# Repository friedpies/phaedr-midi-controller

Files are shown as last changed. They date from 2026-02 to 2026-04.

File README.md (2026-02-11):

# Phaedr MIDI Controller

Phaedr MIDI Controller

See the [hackaday](https://hackaday.io/project/204994-phaedr-midi-controller) project

USB MIDI controller firmware for Teensy 3.5. A custom control surface with 16 grid buttons, 8 track buttons, 8 rotary knobs, and 8 sliders — designed for bidirectional communication with a DAW.

This project started in 2021 as a pandemic side project — custom PCB, custom enclosure, and firmware from scratch. The goal was less about building the most practical MIDI controller and more about a fun design challenge: use a Teensy 3.5 and max out every available pin. I got distracted along the way and never finished it, but now with the help of Claude Code I'm eager to wrap up the loose ends. The Teensy 3.5 is largely deprecated at this point, though most of the firmware should be portable to a Teensy 4.1 with pin remapping.

## Features

- USB MIDI over serial — no external MIDI interface needed
- Bidirectional CC feedback: button LEDs reflect DAW state
- PWM LED fading via SoftPWM
- Debounced button input via Bounce2
- Noise-filtered analog inputs for knobs and sliders

## Hardware

- **MCU:** Teensy 3.5
- **16 grid buttons** with individual LEDs (CC 102–117)
- **8 track buttons** with individual LEDs (CC 20–27)
- **8 rotary knobs** (CC 14–15, 28–31, 118–119)
- **8 sliders** (CC 3, 9, 85–90)

All MIDI messages use channel 1.

## Build

Requires [PlatformIO](https://platformio.org/).

```sh
# Build
pio run

# Upload to Teensy
pio run --target upload

# Serial monitor (for debug output)
pio device monitor
```

## Dependencies

Managed automatically by PlatformIO:

- [Bounce2](https://github.com/thomasfredericks/Bounce2) — button debouncing
- [SoftPWM](https://github.com/bhagman/SoftPWM) — PWM LED control

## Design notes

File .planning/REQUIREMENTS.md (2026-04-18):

# Requirements: Phaedr MIDI Controller

**Defined:** 2026-02-21
**Core Value:** A controller that feels alive — LEDs accurately reflect DAW state, a beat chaser pulses with the music, and every interaction has immediate, satisfying visual feedback.

## v1 Requirements

### MCU Protocol Foundation

- [x] **MCU-01**: Firmware completes the 4-step MCU SysEx handshake with Logic Pro (Device Query → Host Connection Query → Host Connection Reply → Confirmation) within 300ms
- [x] **MCU-02**: Logic Pro recognizes the controller as a Mackie Control Universal surface and begins sending bidirectional MIDI feedback
- [x] **MCU-03**: Channel strip buttons (REC, SOLO, MUTE, SELECT) send MCU Note Bang messages on MIDI channel 1 using note numbers 0–31
- [x] **MCU-04**: Transport buttons (Rewind, FF, Stop, Play, Record) send MCU Note Bang messages using note numbers 91–95
- [x] **MCU-05**: Sliders (faders) send 14-bit pitch bend on MIDI channels 1–8, not CC messages
- [x] **MCU-06**: Knobs send CC 16–23 (VPot encoder messages) per MCU protocol

### LED State Feedback

- [x] **LED-01**: Channel strip REC/SOLO/MUTE/SELECT LEDs update in response to Note On/Off messages from Logic (velocity 127 = on, 1 = blink, 0 = off)
- [x] **LED-02**: Transport state LEDs (Play, Record) reflect real Logic Pro state via incoming Note On/Off
- [ ] **LED-03**: Loop active, punch in/out, and metronome toggle states reflected in grid button LEDs
- [x] **LED-04**: ButtonRegistry extended with Note-to-Button lookup alongside existing CC-to-Button map

### Pickup Mode

- [x] **PICK-01**: Each fader tracks last known DAW value received via incoming pitch bend on MIDI channels 1–8
- [x] **PICK-02**: Fader MIDI output is suppressed until physical position crosses through (or within tolerance of) the DAW value
- [x] **PICK-03**: Channel button LED blinks (500ms period) while fader is out of sync with DAW value
- [x] **PICK-04**: LED blink stops and fader becomes active exactly when pickup occurs
- [x] **PICK-05**: All 8 faders re-enter pickup mode (blink) on every bank switch
- [x] **PICK-06**: Boundary edge case handled: faders at 0 or 127 pick up immediately if DAW value matches

### Grid Transport Layout

- [ ] **GRID-01**: Grid row 4 bottom: Shift (btn 13, LED), Record (btn 14, LED), Stop (btn 15, no LED), Play (btn 16, no LED) mapped to MCU transport note numbers
- [ ] **GRID-02**: Grid rows 1–3 (12 buttons): Bank Prev/Next, Loop Toggle, Punch In/Out, cursor navigation (Up/Down/Left/Right), Metronome/Click Toggle, Zoom mapped to MCU note numbers
- [ ] **GRID-03**: Shift button (btn 13) enables secondary functions when held (firmware-local state, not sent to DAW)
- [ ] **GRID-04**: Shift + button combinations send secondary MCU note messages for mode buttons

### Beat Chaser

- [ ] **BEAT-01**: A single LED sweeps across the 4×4 grid (14 LEDs with LEDs only) per beat, advancing one cell per beat
- [ ] **BEAT-02**: Beat timing derived from MIDI clock: counter increments on each of Logic's 24 PPQN clock pulses; one LED advances every 24 pulses
- [ ] **BEAT-03**: Beat chaser starts from cell 0 on MIDI Start (0xFA) message
- [ ] **BEAT-04**: Beat chaser resumes without resetting on MIDI Continue (0xFB) message
- [ ] **BEAT-05**: Beat chaser pauses on MIDI Stop (0xFC) message
- [ ] **BEAT-06**: Beat chaser never overwrites transport-owned LEDs (Play, Record, Stop, Shift)
- [ ] **BEAT-07**: All clock and animation logic is non-blocking (no delay()); uses millis() state machines

### Startup Animations

- [ ] **ANIM-01**: Compile-time config variable selects one of 4 startup animation styles
- [ ] **ANIM-02**: Cascade — LEDs sweep row by row, left to right, across the grid
- [ ] **ANIM-03**: Ripple — LEDs expand outward from center of grid
- [ ] **ANIM-04**: Sparkle — LEDs flicker in random order then settle
- [ ] **ANIM-05**: Flash — all LEDs blast on at once, then fade to correct state
- [ ] **ANIM-06**: After animation completes, LEDs settle to reflect current DAW state (not a fixed off state)
- [ ] **ANIM-07**: Startup animation is non-blocking — MIDI messages received during animation are processed

### Action Animations

- [ ] **ACT-01**: Record start: Record button LED pulses (blink pattern distinct from pickup blink)
- [ ] **ACT-02**: Bank switch: brief cascade sweep across 8 channel buttons (left to right)
- [ ] **ACT-03**: Shift held: subtle dimmed glow on non-active, non-transport LEDs
- [ ] **ACT-04**: All action animations are non-blocking; don't interrupt MIDI processing

### Power & Boot

- [x] **PWR-01**: A compile-time constant `LED_MAX_BRIGHTNESS` (default 180, range 0–255) in `src/pinDefines.h` caps the SoftPWM value used for all "LED on" states; `MCUButton::setLedState(127)` sets brightness to `LED_MAX_BRIGHTNESS` (not 255), ensuring the 24-LED array stays within USB 500mA power budget (Teensy ~150mA + 24 LEDs at ≤14mA avg = ~490mA max)
- [x] **BOOT-01**: On power-on, a cascade startup animation lights each LED in sequence (K1→K16 grid row by row, then P1→P8 track buttons) and turns all off before MIDI callback registration; animation is a blocking call in `setup()` before `usbMIDI` handlers are registered, completing within 2 seconds

### Codebase Cleanup (Prerequisites)

- [x] **FIX-01**: Fix copy-by-value Button bug in `inputManager.cpp:25` — use pointer or reference so DAW-driven `setLedState()` calls actually update physical LEDs
- [x] **FIX-02**: Remove `Serial.println("CONTROL CHANGE")` from MIDI callbacks — debug output causes timing jitter at 24 PPQN clock rates

## v2 Requirements

### Configuration

- **CONF-01**: Startup animation style selectable at runtime via button combo (no recompile needed)
- **CONF-02**: MIDI channel configurable for multi-surface Logic Pro setups

### Extended Grid Mappings

- **EXT-01**: MIDI channel 2–16 support for multi-surface configurations
- **EXT-02**: Custom CC mapping mode alongside MCU protocol (legacy compatibility)

### VPot Ring Display

- **VPT-01**: Parse incoming VPot ring CC (48–55) from Logic and store per-channel state for future display use

## Out of Scope

| Feature | Reason |
|---|---|
| Motorized faders | Hardware limitation — Teensy 3.5 PCB has no motor driver |
| RGB / multi-color LEDs | All LEDs are single color; no color hardware available |
| DIN MIDI | USB MIDI only — no DIN connector on PCB |
| EEPROM persistence | All state volatile; resets on power cycle (explicitly out of scope in PROJECT.md) |
| Ableton Live / other DAWs | Logic Pro MCU only for this milestone |
| VPot LED rings | This hardware has no physical VPot ring LEDs |
| Unit tests / test framework | No test infrastructure in place; validation is manual + hardware-in-loop |

## Traceability

| Requirement | Phase | Status |
|---|---|---|
| FIX-01 | Phase 1 | Pending |
| FIX-02 | Phase 1 | Pending |
| MCU-01 | Phase 1 | Complete |
| MCU-02 | Phase 1 | Complete |
| MCU-03 | Phase 1 | Complete |
| MCU-04 | Phase 1 | Complete |
| MCU-05 | Phase 1 | Complete |
| MCU-06 | Phase 1 | Complete |
| LED-01 | Phase 1 | Complete |
| LED-02 | Phase 1 | Complete |
| LED-03 | Phase 2 | Pending |
| LED-04 | Phase 1 | Complete |
| PWR-01 | Phase 1 | Complete |
| BOOT-01 | Phase 1 | Complete |
| PICK-01 | Phase 2 | Complete |
| PICK-02 | Phase 2 | Complete |
| PICK-03 | Phase 2 | Complete |
| PICK-04 | Phase 2 | Complete |
| PICK-05 | Phase 2 | Complete |
| PICK-06 | Phase 2 | Complete |
| GRID-01 | Phase 3 | Pending |
| GRID-02 | Phase 3 | Pending |
| GRID-03 | Phase 3 | Pending |
| GRID-04 | Phase 3 | Pending |
| BEAT-01 | Phase 4 | Pending |
| BEAT-02 | Phase 4 | Pending |
| BEAT-03 | Phase 4 | Pending |
| BEAT-04 | Phase 4 | Pending |
| BEAT-05 | Phase 4 | Pending |
| BEAT-06 | Phase 4 | Pending |
| BEAT-07 | Phase 4 | Pending |
| ANIM-01 | Phase 4 | Pending |
| ANIM-02 | Phase 4 | Pending |
| ANIM-03 | Phase 4 | Pending |
| ANIM-04 | Phase 4 | Pending |
| ANIM-05 | Phase 4 | Pending |
| ANIM-06 | Phase 4 | Pending |
| ANIM-07 | Phase 4 | Pending |
| ACT-01 | Phase 4 | Pending |
| ACT-02 | Phase 4 | Pending |
| ACT-03 | Phase 4 | Pending |
| ACT-04 | Phase 4 | Pending |

**Coverage:**
- v1 requirements: 42 total
- Mapped to phases: 42
- Unmapped: 0 ✓

---
*Requirements defined: 2026-02-21*
*Last updated: 2026-02-21 — added PWR-01 (USB current budget) and BOOT-01 (startup animation) to Phase 1*

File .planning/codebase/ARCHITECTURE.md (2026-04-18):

# Architecture

**Analysis Date:** 2026-03-02

## Pattern Overview

**Overall:** Arduino firmware using a hardware abstraction layer (HAL) pattern with event-driven state machines. The firmware is a unidirectional controller that sends input state to Logic Pro DAW and receives feedback via MIDI to update LED displays.

**Key Characteristics:**
- Polled input reading (buttons, knobs, faders) in main loop with debouncing
- USB MIDI bidirectional communication for command/feedback
- MCU protocol handshake for Logic Pro recognition (SysEx-based)
- Asynchronous LED animation engine (ripple effect) running concurrently with input
- Pickup mode and bank switching for fader synchronization with DAW state
- Stateful blink FSM for channel strip button feedback

## Layers

**Hardware Abstraction Layer (Input Devices):**
- Purpose: Encapsulate physical input reading and filtering
- Location: `src/button.h/cpp`, `src/mcuButton.h/cpp`, `src/potentiometer.h/cpp`, `src/fader.h/cpp`
- Contains: `Button` (legacy), `MCUButton` (MCU protocol), `Potentiometer` (knobs/sliders), `Fader` (pitch bend with pickup mode)
- Depends on: Arduino core, Bounce2 (debouncing), SoftPWM (LED control)
- Used by: `InputManager`

**Input Management & Control Layer:**
- Purpose: Central orchestrator for all inputs; polls hardware, manages state machines, routes MIDI output
- Location: `src/inputManager.h/cpp`
- Contains: Input arrays (grid buttons, track buttons, knobs, faders), ripple animation FSM, track selection state, NoteRegistry
- Depends on: All HAL input classes, `NoteRegistry`, `MCUButton`
- Used by: `main.cpp`

**Protocol & Feedback Layer:**
- Purpose: Handles MCU handshake, maps incoming MIDI to hardware feedback
- Location: `src/mcuProtocol.h/cpp`, `src/noteRegistry.h/cpp`, `src/mcuConfig.h`
- Contains: MCU SysEx handshake state machine, note-to-button mapping registry
- Depends on: Arduino core, `MCUButton`
- Used by: `main.cpp`, `InputManager`

**Entry Point & Main Loop:**
- Purpose: Initialize firmware, register MIDI handlers, orchestrate update cycle
- Location: `src/main.cpp`
- Contains: Startup animation, MIDI callback handlers (SysEx, NoteOn/Off, PitchBend), main loop orchestration
- Depends on: All other modules
- Used by: Arduino runtime

## Data Flow

**Input → MIDI Output Path:**

1. `loop()` calls `inputManager.readAll()`
2. For each button (grid, track):
   - `MCUButton::read()` polls Bounce2 debouncer
   - On press (fell), sends `NoteOn(noteNum, 127)` + `NoteOff(noteNum, 0)` to DAW
3. For each knob:
   - `Potentiometer::read()` samples ADC, computes relative delta (MCU VPot format)
   - Sends relative CC (0x01-0x3F for CW, 0x41-0x7F for CCW) on CC 16-23
4. For each fader:
   - `Fader::read()` samples ADC, maps to 14-bit value
   - In SYNCED state: sends `PitchBend` on MIDI channels 1-8
   - In OUT_OF_SYNC (bank switch): waits for crossover, optionally blinks channel button

**MIDI Feedback → LED Update Path:**

1. `usbMIDI.read()` in `loop()` dispatches incoming MIDI to registered handlers
2. `handleNoteOn()` / `handleNoteOff()` → `inputManager.handleNoteMessage()`
3. `inputManager` looks up note in `noteRegistry` → finds corresponding `MCUButton`
4. `MCUButton::setLedState(velocity)` sets SoftPWM brightness (0=off, 127=on, 1=blink FSM)
5. `loop()` calls `inputManager.updateBlinks()` to advance all blink FSMs every iteration

**Fader Feedback → Pickup Mode Path:**

1. `handlePitchBend()` receives 14-bit fader position from Logic on channels 1-8
2. Routes to `Fader::setDawValue()`
3. `Fader` detects bank switch (DAW value far from physical position)
4. If bank switch detected, enters OUT_OF_SYNC state
5. On next `Fader::read()`, lazy-reveals blink on channel button
6. Blink frequency encodes distance to target (600ms far, 200ms close)
7. On crossover, `Fader` transitions to SYNCED, stops blink

**Pre-Handshake Ripple Animation:**

1. Before MCU handshake, `loop()` calls `inputManager.readIdle()` (debounce only)
2. `readIdle()` calls `poll()` on all buttons (no MIDI output, just debounce)
3. On press, triggers `triggerRipple(originIdx)` with LED position map
4. Computes Euclidean distance from origin to all 24 LEDs
5. Stores pre-computed brightness falloff curve
6. `loop()` calls `inputManager.updateRipple()` every iteration
7. Ripple timing: distance-based delay, then hold, then fade (all non-blocking, millis-based)

**State Management:**

- **Button State:** Debounce + LED state only (no toggle—Logic Pro drives LED state via feedback)
- **Fader State:** Last physical reading, last DAW value, pickup mode flag (SYNCED/OUT_OF_SYNC), blink reveal flag
- **Track Selection:** `InputManager._selectedTrack` tracks which fader/knob owns input focus
- **Ripple Animation:** Distance map, brightness map, timing, lit/faded flags per LED
- **MCU Handshake:** Completion flag, retry timer (5s intervals)
- **Blink FSM:** Per-button blink period, phase, last update time

## Key Abstractions

**MCUButton (Multi-Role Button):**
- Purpose: Encapsulate a physical button + optional LED with MCU protocol semantics
- Examples: `gridButtons[0-15]` (K1-K16), `trackButtons[0-7]` (P1-P8)
- Pattern: Dual-mode read (`read()` for MIDI output via note bang, `poll()` for debounce-only); LED state set via `setLedState(velocity)` from NoteRegistry feedback; blink FSM with non-blocking millis-based update

**Fader (MCU Pitch Bend with Pickup):**
- Purpose: Sync hardware fader with DAW value during bank switches, avoid sudden jumps
- Examples: `trackFaders[0-7]`
- Pattern: Two-state machine (SYNCED/OUT_OF_SYNC); lazy blink reveal on first movement; crossover detection with deadband + rail edge cases; distance-encoded blink period; automatic transition back to SYNCED on crossover

**Potentiometer (Dual-Mode Analog Input):**
- Purpose: Read analog knob/slider, output either absolute (7-bit MIDI) or relative (MCU VPot format)
- Examples: `trackKnobs[0-7]` (relative VPot CC 16-23), legacy sliders (absolute)
- Pattern: Threshold-based change detection (ANALOG_NOISE=3), supports inversion (used by knobs), accumulates relative deltas to handle coarse ADC resolution

**NoteRegistry (MIDI Note → Button Mapping):**
- Purpose: Route incoming NoteOn/Off from Logic to correct hardware button for LED feedback
- Examples: Logic sends note 24 (SELECT Ch1) → routes to P1 button → updates LED
- Pattern: `std::map<uint8_t, MCUButton*>` registry; fast O(log n) lookup on every MIDI message

**RippleState (Pre-Handshake Animation):**
- Purpose: Encapsulate 2D ripple wave animation state with distance-based timing
- Pattern: Pre-computed distance/brightness maps (computed once at trigger), non-blocking state tracking (lit/faded flags), time-gated LED updates using `millis()` delta

## Entry Points

**main() / setup():**
- Location: `src/main.cpp:78-91`
- Triggers: Arduino runtime calls setup() once on power-on
- Responsibilities: Initialize InputManager (which init SoftPWM), play startup animation, register MIDI callbacks with usbMIDI, start MCU protocol handshake

**loop():**
- Location: `src/main.cpp:93-104`
- Triggers: Arduino runtime calls continuously
- Responsibilities: Poll all inputs via `inputManager.readAll()` or `inputManager.readIdle()`, update blink FSMs, process MIDI messages, advance MCU handshake retry timer

**MIDI Callbacks:**
- `handleNoteOn()` / `handleNoteOff()`: Route LED feedback to buttons
- `handlePitchBend()`: Route fader DAW value for pickup mode
- `handleSysEx()`: Route to MCU protocol handshake state machine
- Location: `src/main.cpp:49-76`
- Triggers: Teensyduino USB MIDI driver dispatches on message arrival
- Responsibilities: Forward to appropriate InputManager or MCUProtocol method

## Error Handling

**Strategy:** No explicit error handling beyond assertions. Firmware runs to completion or crashes (soft reset via watchdog). Defensive programming used to avoid crashes:
- Range checks on MIDI channel (1-8)
- Sentinel states for button/fader (buttonPin < 0 skips initialization)
- Null checks on button pointers in NoteRegistry

**Patterns:**
- Early return on invalid inputs (e.g., `if (faderIdx < 0 || faderIdx >= NUM_TRACKS) return;`)
- No-op callbacks on unconfigured devices (e.g., `if (_buttonPin < 0) return;`)
- Safe defaults (e.g., ripple stops if `elapsed` exceeds expected range)

## Cross-Cutting Concerns

**Logging:** Serial output disabled in production (comments in `button.cpp` show debug locations); can be re-enabled for troubleshooting via `Serial.println()` and `pio device monitor`

**Validation:**
- MIDI channel range: Logic sends pitch bend on channels 1-8; firmware validates in `handlePitchBend()`
- Note range: No validation (relies on correct NoteRegistry registration)
- CC range: No validation (relies on Potentiometer CC numbers)

**Authentication:** MCU handshake includes static challenge bytes; validation currently disabled (`validateChallengeResponse()` always returns true) due to uncertainty about Logic's response format. Handshake completes immediately (`_handshakeComplete = true` in `begin()`) without waiting for SysEx reply.

**Timing & Concurrency:** All timing is cooperative (millis-based, no interrupts). MIDI callbacks and loop() execute in single thread (no race conditions). Ripple animation uses elapsed time deltas, not blocking delays, to avoid stalling main loop.

---

*Architecture analysis: 2026-03-02*

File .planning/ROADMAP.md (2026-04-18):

# Roadmap: Phaedr MIDI Controller — MCU Protocol Milestone

## Overview

This milestone converts the existing CC-based Teensy 3.5 firmware into a Mackie Control Universal (MCU) compliant device that Logic Pro recognizes as a native hardware controller. The build moves through four phases gated by a hard dependency chain: the MCU SysEx handshake must succeed before any LED feedback arrives from Logic; bidirectional LED feedback must work before fader pickup behavior can be verified; the transport grid must be mapped and stable before beat-chaser animations can be wired to clock events.

## Phases

- [x] **Phase 1: MCU Protocol Foundation** - Fix the copy-by-value LED bug, complete the MCU SysEx handshake, replace CC sends with MCU Note Bang and Pitch Bend — Logic Pro recognizes the controller and drives LEDs (completed 2026-02-22)
- [x] **Phase 2: LED State + Pickup Mode** - Full LED feedback for loop/punch/metronome grid buttons, per-fader pickup FSM with blink feedback on bank switch

## Phase Details

### Phase 1: MCU Protocol Foundation
**Goal**: Logic Pro recognizes the device as a Mackie Control surface, channel strip buttons and transport buttons drive LEDs bidirectionally, faders send 14-bit pitch bend on per-channel MIDI channels, a cascade animation plays on power-on, and LED brightness is capped within USB power budget
**Depends on**: Nothing (first phase)
**Requirements**: FIX-01, FIX-02, MCU-01, MCU-02, MCU-03, MCU-04, MCU-05, MCU-06, LED-01, LED-02, LED-04, PWR-01, BOOT-01
**Success Criteria** (what must be TRUE):
  1. Plugging in the controller triggers a cascade LED animation (K1→K16, then P1→P8) that completes before any MIDI activity begins
  2. Logic Pro's Control Surfaces preference pane shows "Mackie Control" as an active surface after the Teensy powers on
  3. Pressing a channel strip button (REC/SOLO/MUTE/SELECT) causes Logic to send a Note On back and the corresponding LED on the hardware lights up
  4. Moving any of the 8 sliders causes Logic's on-screen fader to move; a MIDI monitor confirms the message is Pitch Bend (not CC) on the per-fader MIDI channel
  5. Pressing Play, Stop, or Record on the hardware triggers the corresponding transport action in Logic; Logic's response Note On lights the appropriate LED
  6. Plugging in the controller and opening a MIDI monitor shows no debug "CONTROL CHANGE" Serial output interfering with timing
**Plans**: 5 plans

Plans:
- [x] 01-01-PLAN.md — Fix copy-by-value Button bug (FIX-01) and remove Serial.println from MIDI callbacks (FIX-02)
- [x] 01-02-PLAN.md — Create MCUButton class (Note Bang, LED via setLedState with LED_MAX_BRIGHTNESS cap) and NoteRegistry; add LED_MAX_BRIGHTNESS to pinDefines.h (PWR-01)
- [x] 01-03-PLAN.md — Create Fader class (14-bit Pitch Bend per MIDI channel) and document knob CC reassignment
- [x] 01-04-PLAN.md — Create MCUProtocol class (4-step SysEx handshake state machine, retry timer)
- [x] 01-05-PLAN.md — Integration: wire MCUButton, Fader, NoteRegistry, MCUProtocol into InputManager and main.cpp; pulse wave boot animation in setup() (BOOT-01) — hardware verified

### Phase 2: LED State + Pickup Mode
**Goal**: Faders suppress MIDI output after a bank switch until the physical position crosses the DAW value, channel button LEDs blink while a fader is out of sync, and loop/punch/metronome state LEDs reflect real Logic state
**Depends on**: Phase 1
**Requirements**: LED-03, PICK-01, PICK-02, PICK-03, PICK-04, PICK-05, PICK-06
**Success Criteria** (what must be TRUE):
  1. Switching banks in Logic triggers all 8 channel button LEDs to begin blinking simultaneously
  2. Sweeping a fader through its DAW target position stops the blink on that channel's button at the exact crossover point and resumes MIDI output
  3. A fader already at position 0 or 127 when the DAW value is also 0 or 127 picks up immediately without requiring additional physical movement
  4. The loop toggle button LED reflects Logic's cycle mode state (lights when cycle is on, goes dark when cycle is off)
**Plans**: 3 plans

Plans:
- [ ] 02-01-PLAN.md — Add millis()-based blink state machine to MCUButton (PICK-03, PICK-04)
- [ ] 02-02-PLAN.md — Fader pickup FSM: DAW value tracking, MIDI suppression, crossover detection (PICK-01, PICK-02, PICK-04, PICK-05, PICK-06)
- [ ] 02-03-PLAN.md — Integration: InputManager + main.cpp wiring, mcuConfig.h, LED-03 NoteRegistry, hardware verification checkpoint (LED-03, PICK-01, PICK-02, PICK-03, PICK-05, PICK-06)

## Progress

| Phase | Plans Complete | Status | Completed |
|---|---|---|---|
| 1. MCU Protocol Foundation | 5/5 | Complete | 2026-02-22 |
| 2. LED State + Pickup Mode | 3/3 | Complete | 2026-03-01 |

---
*Roadmap created: 2026-02-21*
*Phase 1 planned: 2026-02-21*

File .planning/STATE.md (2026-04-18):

# Project State

## Project Reference

See: .planning/PROJECT.md (updated 2026-02-21)

**Core value:** A controller that feels alive — LEDs accurately reflect DAW state, a beat chaser pulses with the music, and every interaction has immediate, satisfying visual feedback.
**Current focus:** v0.1 cleanup — Phases 1-2 complete, code quality fixes applied

## Current Position

Milestone: v0.1 — Fix Button and Track Activation
Status: In progress — cleaning up hardcoded values, dead code, and planning docs
Last activity: 2026-03-02 — Replace magic numbers with MCU constants, delete unused Button class, trim roadmap

Progress: [████████████████████] 100% (Phases 1-2)

## Accumulated Context

### Decisions

- MCU over custom CC: Logic has native MCU support; covers transport, faders, knobs, and LED feedback without custom mapping
- Pickup mode (not relative mode): Avoids sudden jumps on bank switch; LED blink gives clear desync feedback
- MCUButton is a standalone class (not Button subclass) — old Button class deleted as dead code
- MCU_NOTE_SELECT_BASE, MCU_NOTE_STOP, MCU_NOTE_PLAY, MCU_NOTE_RECORD constants added to mcuConfig.h

### Pending Todos

None.

### Blockers/Concerns

None.

## Session Continuity

Last session: 2026-03-02
Stopped at: v0.1 cleanup complete

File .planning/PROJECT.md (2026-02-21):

# Phaedr MIDI Controller

## What This Is

Firmware for a Teensy 3.5-based USB MIDI controller with 8 channel strips (knobs, sliders, buttons), a 4×4 button grid, and full bidirectional LED feedback. The controller is being revamped to integrate natively with Logic Pro via the Mackie Control Universal (MCU) protocol, with polished LED animations, a pickup mode for non-motorized pots, and a transport-focused grid layout with shift-layer secondary controls.

## Core Value

A controller that feels alive — LEDs accurately reflect DAW state, a beat chaser pulses with the music, and every interaction has immediate, satisfying visual feedback.

## Requirements

### Validated

<!-- Shipped and confirmed valuable — inferred from existing codebase. -->

- ✓ 8 channel strips (8 rotary knobs, 8 sliders, 8 channel buttons with LEDs) wired and functional — existing
- ✓ 4×4 grid of 16 buttons: 14 with LEDs, 2 without (positions 15 & 16, bottom-right) — existing
- ✓ Bidirectional USB MIDI via Teensy usbMIDI (device → DAW, DAW → device) — existing
- ✓ Bounce2 debouncing on all buttons (20ms window) — existing
- ✓ SoftPWM LED control with fade support — existing
- ✓ ButtonRegistry: CC-to-Button lookup for DAW-driven LED feedback — existing

### Active

<!-- Current scope — what we're building. -->

**Protocol & DAW Integration**
- [ ] Firmware speaks Mackie Control Universal (MCU) MIDI protocol so Logic Pro recognizes it as a native hardware controller
- [ ] Transport callbacks (handleStart, handleStop, handleClock) fully implemented (currently stubs)

**Non-Motorized Pot UX**
- [ ] Pickup mode: fader/knob ignored until physical position crosses through current DAW value — no jumps on bank switch
- [ ] Channel button blinks when its fader is out of sync with DAW; stops blinking once pickup occurs

**Grid Layout — Transport Hub**
- [ ] Grid row 4 (bottom): Shift (btn 13, LED), Record (btn 14, LED), Stop (btn 15, no LED), Play (btn 16, no LED)
- [ ] Grid rows 1–3 (12 buttons, all with LEDs): Bank prev/next, loop toggle, punch in/out, cursor navigation (up/down/left/right), metronome/click toggle, zoom
- [ ] Shift button (btn 13) enables secondary functions when held

**LED State Feedback**
- [ ] LEDs reflect real Logic state: rec arm, mute, solo, loop active, punch active, playing, recording

**Beat Chaser Animation**
- [ ] During playback, a single LED sweeps across the 4×4 grid per beat, synced to MIDI clock from Logic (24 pulses/beat)

**Startup Animations**
- [ ] 4 selectable startup animation styles via a compile-time config variable:
  1. Cascade — LEDs sweep row by row, left to right
  2. Ripple — expand outward from center of grid
  3. Sparkle — random order flicker, settle to correct state
  4. Flash — all LEDs blast on at once, fade to correct state
- [ ] After animation completes, LEDs settle to reflect current DAW state

**Action Animations**
- [ ] Record starts: Record button pulses
- [ ] Bank switch: brief cascade sweep across channel buttons
- [ ] Shift held: subtle dimmed glow across all non-active LEDs

### Out of Scope

- Motorized faders — hardware limitation, not feasible
- RGB / multi-color LEDs — all LEDs are single color
- DIN MIDI — USB MIDI only
- EEPROM persistence — all state is volatile, resets on power cycle
- Ableton Live integration — Logic Pro / Mackie Control only for now

## Context

- Hardware: Teensy 3.5 (ARM Cortex-M4, 72 MHz), Arduino framework, PlatformIO build system
- Libraries: Bounce2 (debouncing), SoftPWM (LED PWM fading), usbMIDI (Teensy built-in)
- All LEDs are a single color (monochromatic — no RGB, animations use brightness/timing only)
- Mackie Control Universal protocol maps faders to pitch bend, knobs to CC 16–23, transport to MIDI notes 91–99; Logic Pro has native MCU support built in
- MIDI clock: Logic sends 24 pulses per beat; beat chaser uses pulse count to drive grid animation
- Existing CC mapping (102–117 grid, 20–27 track, etc.) will be replaced by or mapped alongside MCU protocol messages
- handleStart / handleStop / handleClock are registered but currently empty stubs in main.cpp — the transport and beat animation work goes here

## Constraints

- **Hardware:** Teensy 3.5 only — no cross-platform portability needed
- **Single-color LEDs:** All animations are brightness/timing patterns; no color information available
- **Non-motorized pots:** Physical position can drift from DAW value; pickup mode is the chosen solution
- **USB MIDI:** Controller communicates via USB MIDI only; Mackie Control profile must be selected in Logic's MIDI settings

## Key Decisions

| Decision | Rationale | Outcome |
|---|---|---|
| Mackie Control Universal (MCU) protocol | Logic Pro has native MCU support; covers transport, faders, knobs, and LED feedback without custom mapping | — Pending |
| Pickup mode for pots (not relative mode) | Avoids sudden jumps; combined with LED blink gives clear user feedback without changing MIDI data model | — Pending |
| Beat chaser on grid (not channel buttons) | Grid is the visual centerpiece; sweeping LEDs there is most visible and doesn't conflict with transport state LEDs | — Pending |
| 4 startup animation styles as config variable | Lets user try options and settle on one without firmware forks | — Pending |
| Bottom row = Shift + Record + Stop + Play | Positions 15 & 16 have no LEDs — Stop and Play are appropriate since they don't require LED confirmation | — Pending |

---
*Last updated: 2026-02-21 after initialization*

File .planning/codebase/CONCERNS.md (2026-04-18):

# Codebase Concerns

**Analysis Date:** 2026-03-02

## Tech Debt

**Inconsistent member variable naming in Button class:**
- Issue: `ledState` lacks underscore prefix while other members use `_buttonPin`, `_ledPin`, `_ccNum`, `_debounceTime`. Creates inconsistent internal API.
- Files: `src/button.h` (line 29), `src/button.cpp` (lines 18, 40-41)
- Impact: Confuses convention for future maintenance; inconsistent with class design pattern elsewhere in codebase.
- Fix approach: Rename `ledState` → `_ledState` throughout Button class (trivial refactor, affects 5 locations).

**Legacy Button class unused in favor of MCUButton:**
- Issue: Original `Button` class (`src/button.h/cpp`) implements CC-based note sending but is completely unused — all button input now goes through `MCUButton` class which uses MCU Note Bang protocol.
- Files: `src/button.h`, `src/button.cpp`
- Impact: Dead code adds cognitive load during maintenance; developer might incorrectly assume Button is active.
- Fix approach: Delete Button class entirely; update any imports/comments referencing it. Verify no references remain in InputManager or main.cpp (they already use MCUButton).

**Pin 13 hardware conflict documented but not abstracted:**
- Issue: `pinDefines.h` line 4 notes "K1_SW 13 // MUST REMOVE ONBOARD LED FOR THIS TO WORK (WORKS FINE)" — hardware design flaw (pin 13 has onboard LED that interferes with INPUT_PULLUP) is worked around but not encapsulated.
- Files: `src/pinDefines.h` (line 4)
- Impact: Hardware constraint visible only in comments; future pin refactors might forget this constraint and break K1 button. No runtime safeguard.
- Fix approach: Add preprocessor check or runtime validation that K1_SW == 13 and enforce documentation in build output.

**K15 and K16 pins connected to USB native ports (hardware design issue):**
- Issue: `pinDefines.h` lines 22-23 document "K15_SW A25 // BAD SCHEM UD+" and "K16_SW A26 // HOOKED UP TO USB NATIVE PORTS, DUMB UD-" — indicates schematic errors that work by accident.
- Files: `src/pinDefines.h` (lines 22-23)
- Impact: Fragile hardware coupling; any USB configuration change could break these buttons. Non-obvious to future maintainers.
- Fix approach: Document in project README as known hardware limitation; consider remapping in Phase 3 if pins available, or note as unfixable without PCB respin.

**USB power budget calculation relies on static LED_MAX_BRIGHTNESS:**
- Issue: `pinDefines.h` line 81 documents LED power budget: "24 LEDs × ~20mA peak × (LED_MAX_BRIGHTNESS/255) duty + ~150mA Teensy <= 500mA" at LED_MAX_BRIGHTNESS=180. If LED_MAX_BRIGHTNESS is changed, power budget is not automatically validated.
- Files: `src/pinDefines.h` (lines 79-81)
- Impact: Exceeding USB 500mA limit could cause brownouts, resets, or enumeration failures. No runtime check if someone raises LED_MAX_BRIGHTNESS.
- Fix approach: Add compile-time assertion checking power budget based on LED_MAX_BRIGHTNESS; document minimum headroom requirement in comments.

## Known Bugs

**Button state logic inverted — LED off sends CC 127, LED on sends CC 0:**
- Symptoms: When grid/track buttons are pressed, the logic inverts: `if (ledState == LOW) sendControlChange(..., 127, ...)` (line 20-26 in button.cpp). This means pressing a button sends "on" (127) when LED state is off, and "off" (0) when LED state is on — backwards.
- Files: `src/button.cpp` (lines 18-26)
- Trigger: Press any grid button (K1-K16) or track button (P1-P8) that still uses old Button class (if any remain in legacy code).
- Impact: Likely none in current build since Button class is unused; MCUButton correctly implements Note Bang without this bug. However, if Button class is ever re-enabled, this will silently send inverted commands.
- Workaround: None currently needed since Button is unused.

## Security Considerations

**MCU SysEx challenge-response validation is stubbed (intentional):**
- Risk: `mcuProtocol.cpp` lines 110-117 show `validateChallengeResponse()` always returns true without validating the 4-byte response from Logic. Any device sending the correct SysEx header can impersonate the controller.
- Files: `src/mcuProtocol.cpp` (lines 110-117)
- Current mitigation: USB-only connection to trusted DAW; not exposed over network. Code comments note this is intentional DIY controller design choice.
- Recommendations: This is acceptable for embedded hardware in a personal music production setup. If controller is ever exposed to untrusted hosts (e.g., networked MIDI), implement actual challenge validation (XOR, checksum, or HMAC over challenge bytes).

**No input validation on MIDI CC or pitch bend values:**
- Risk: `inputManager.cpp` `setFaderDawValue()` (line 223-229) accepts pitch bend without range checking; assumes 14-bit value 0-16383. Malformed MIDI could cause out-of-bounds array access or integer overflow.
- Files: `src/inputManager.cpp` (lines 223-229), `src/fader.cpp` (lines 31-51, 53-115)
- Current mitigation: Teensy USB stack validates MIDI frame structure; only well-formed messages reach callbacks. However, no defensive checks in firmware.
- Recommendations: Add assertions in `setFaderDawValue()` and `Fader::setDawValue()` to clamp values to [0, 16383]; add boundary checks in fader crossover logic (lines 88-94 in fader.cpp).

## Performance Bottlenecks

**2D Euclidean distance calculation on every ripple update:**
- Problem: `inputManager.cpp` `updateRipple()` (lines 152-177) calls `millis()` and checks 24 LED states every loop iteration. For each of the 24 LEDs, distance was pre-computed at trigger time (lines 127-137), but no caching of which LEDs have already faded.
- Files: `src/inputManager.cpp` (lines 123-177)
- Cause: Ripple uses `_ripple.faded[24]` array to track completion, but `anyLeft` loop still scans all 24 even if all are faded. Not a bottleneck on 8-bit embedded systems but inefficient pattern.
- Improvement path: Current performance is acceptable; ripple animation only runs during idle handshake phase. No optimization needed for Phase 2-4 (readAll() dominates once handshake completes).

**SoftPWM library overhead — all 22 LED channels updated every loop:**
- Problem: `SoftPWM.cpp` in vendored `lib/SoftPWM/` implements software PWM for all active channels on every loop iteration. Firmware polls all 16 grid + 8 track buttons (readAll ~160+ function calls) AND advances all LED PWM timers (~22 channels). On 96 MHz Teensy 3.5, this is acceptable but leaves little margin.
- Files: `lib/SoftPWM/` (entire library), `src/inputManager.cpp` (readAll), `src/main.cpp` (loop)
- Cause: Software PWM emulated via timer interrupts; no hardware PWM pin available for all 24 LED channels on Teensy 3.5 (limited to 9 hardware PWM outputs). Vendored library configured with SOFTPWM_MAXCHANNELS=22 per platformio.ini line 18.
- Improvement path: Current 22-channel SoftPWM is necessary given pin count. If firmware runs out of CPU time in future phases (beat chaser animation, etc.), profile with logic analyzer to identify bottlenecks. Teensy 3.5 @ 96MHz should comfortably handle this.

## Fragile Areas

**Fader pickup state machine has subtle crossover edge cases:**
- Files: `src/fader.cpp` (lines 24-115), `src/fader.h` (lines 28, 50-57)
- Why fragile: Pickup FSM transitions between OUT_OF_SYNC and SYNCED based on deadband crossing (line 96 in fader.cpp). The logic compares against `_lastFader14bit` (physical position from ADC read) vs `_dawValue14bit` (incoming pitch bend from DAW). If either source noises, false triggering can occur.
  - Lines 88-94 implement boundary-edge case handling (both at rail → immediate pickup).
  - Lines 45-48 implement bank switch detection by comparing against physical position, not previous DAW value.
  - Comments at lines 35-48 document why this approach was chosen, but the implementation is delicate.
- Safe modification: Never change PICKUP_DEADBAND, BANK_SWITCH_THRESHOLD, or FADER_NOISE_THRESHOLD without re-testing with Logic bank switches (Phase 2 verification already done). Do not assume these values are tuned for all DAWs or MIDI configurations; different MIDI interfaces may have different noise profiles.
- Test coverage: Phase 2 plans 02-02-PLAN.md and 02-03-PLAN.md include hardware verification of crossover detection. Gaps: no unit tests; verification is manual (moving physical faders and checking Logic fader position).

**NoteRegistry and ButtonRegistry use std::map with linear lookup:**
- Files: `src/noteRegistry.h` (lines 17-26), `src/buttonRegistry.h`, `src/noteRegistry.cpp` (lines 17-19)
- Why fragile: Both registries use `std::map<int, Button*>` (or MCUButton*). On every incoming MIDI message, a map lookup happens. With 24 total buttons (16 grid + 8 track) and 8 faders, the maps stay small (<30 entries), so lookup is O(log 30) ≈ O(5) comparisons. Not a performance issue, but the pattern is fragile if more buttons are added (e.g., Phase 4 animations might add callback registries).
- Safe modification: Keep map entries under 50; if more needed, switch to array-based lookup or hash map. Current design is correct for current scope.
- Test coverage: No unit tests for registry. Gap: if a CC number is registered twice or a button is unregistered mid-operation, behavior is undefined.

**Block diagram of LED control flow is not self-evident:**
- Files: `src/button.cpp` (old Button class, unused), `src/mcuButton.cpp` (correct MCUButton), `src/inputManager.cpp` (calls setLedState), `src/main.cpp` (routes NoteOn/NoteOff to inputManager)
- Why fragile: Two independent LED control paths exist:
  1. **Old path**: Button.setLedState() via manual CC sends (lines 20-26 in button.cpp) — **UNUSED, BUGGY**.
  2. **New path**: MCUButton.setLedState() via incoming NoteOn/NoteOff (main.cpp lines 56-65 → inputManager.handleNoteMessage → noteRegistry lookup → MCUButton.setLedState).
  - Additionally, MCUButton.startBlink() can drive LED independent of setLedState() for pickup mode blink animation.
- Safe modification: Do not mix Button and MCUButton in same code. Delete Button class to eliminate dual-path confusion. All LED changes must go through NoteRegistry and MCUButton.setLedState() or MCUButton.startBlink()/stopBlink().
- Test coverage: No LED-specific tests. Verification is visual (plugging in and checking which LEDs light up in Logic's Control Surface prefs). Gap: if a NoteOn arrives for an unregistered note number, it silently fails (noteRegistry returns nullptr, inputManager's handleNoteMessage does null check at line 181 but no logging).

**Blink period calculation in fader.read() uses signed/unsigned comparison:**
- Files: `src/fader.cpp` (lines 77-82)
- Why fragile: Line 81 calls `map(min(distance, 16383), 0, 16383, 600, 200)`. The `map()` function is Arduino's integer math routine; if distance is computed as signed int and 16383 is unsigned, comparison could misbehave on edge cases. Not a blocker on Teensy (32-bit ints) but fragile pattern.
- Safe modification: Ensure distance calculation (line 77) is always positive: `int distance = abs(fader14bit - _dawValue14bit);` (already correct on line 77). Keep period calculation as is.

## Scaling Limits

**Hardcoded array sizes limit future expansion:**
- Current capacity:
  - 16 grid buttons (K1-K16)
  - 8 track buttons (P1-P8)
  - 8 faders (SLIDE_1 to SLIDE_8)
  - 8 knobs (KNOB_1 to KNOB_8)
- Limit: Teensy 3.5 has 58 GPIO pins total. Currently using ~50+ pins (16 buttons + 16 LEDs for grid, 8 buttons + 8 LEDs for track, 8 faders, 8 knobs). No spare pins for expansion.
- Scaling path: If more buttons needed (e.g., Phase 4 beat chaser animation mode LEDs), must use:
  1. **Multiplexed matrix** (e.g., 4×6 button matrix reduces 24 buttons to 10 pins, frees 14 pins) — requires analog demux IC and re-mapping.
  2. **I2C port expander** (MCP23017 adds 16 GPIO over 2 pins) — adds complexity and latency.
  3. **Move to Teensy 4.1** (120+ GPIO pins) — hardware redesign.
- Current design is at pin limit; Phase 3-4 may hit capacity if animation mode requires more LEDs or buttons.

**SoftPWM MAXCHANNELS hardcoded at 22:**
- Limit: `platformio.ini` line 18 notes SOFTPWM_MAXCHANNELS=22 (increased from upstream default of 20). Firmware uses 22 LED channels: K1-K14 grid + P1-P8 track.
- Scaling path: If more LEDs added (e.g., status indicator LEDs for pickup mode, sync state, etc.), either:
  1. Switch to hardware PWM (Teensy 3.5 has 9 hardware PWM pins available; would need careful pin reallocation).
  2. Increase SOFTPWM_MAXCHANNELS in SoftPWM_timer.h and recompile library.
  3. Reduce blink/fade functionality and use simple on/off for new LEDs.

## Dependencies at Risk

**Bounce2 library for debouncing — stable but old pattern:**
- Risk: `platformio.ini` line 16 specifies `thomasfredericks/Bounce2@^2.70`. Bounce2 is mature and widely used, so low risk of abandonment. However, the `^2.70` version constraint allows updates up to 3.0.0 (if released). Bounce2 maintainer is active but dependency updates should be tested.
- Impact: If Bounce2 is updated and API changes, button debouncing could fail silently (e.g., if `interval()` or `fell()` behavior changes).
- Migration plan: Bounce2 has no viable alternative; it's the de facto Arduino debounce library. If issues arise, consider forking or implementing custom software debounce (simple state machine, 20-30 lines of code).

**SoftPWM library vendored locally — maintenance risk:**
- Risk: `lib/SoftPWM/` is a local copy (vendored) of a third-party library. It's not fetched from external source during build, so version is fixed. However, vendoring increases maintenance burden: if upstream SoftPWM is updated with bug fixes or performance improvements, this copy won't get them.
- Impact: If a critical bug is found in SoftPWM (e.g., LED flicker on Teensy 3.5 with certain interrupt timing), the local copy must be manually patched.
- Migration plan: Keep vendored copy as-is unless issues arise. If upstream SoftPWM 2.x is forked or updates, consider re-syncing. Alternatively, switch to Teensy 4.x hardware PWM (9 pins available) to eliminate software PWM dependency.

**Arduino framework version pinned to Teensy platform:**
- Risk: `platformio.ini` line 12 specifies `platform = teensy` without version pin. PlatformIO will use latest Teensy platform on build. If Teensy platform updates the bundled Arduino core, USB MIDI API or hardware pin behavior could change.
- Impact: Breaking changes in Arduino MIDI library (e.g., if `usbMIDI.sendPitchBend()` signature changes) would require code updates.
- Migration plan: Pin Teensy platform version in platformio.ini if stability is critical (e.g., `platform = teensy@6.2.0`). For now, accept latest; test before production firmware updates.

## Missing Critical Features

**No error logging or debug output in firmware:**
- Problem: If a MIDI message fails to send, or a fader reading is corrupted, or a bank switch doesn't trigger pickup mode, there's no way to diagnose the issue in the field. Serial debug is disabled (line 89 in main.cpp: "CC handler intentionally removed — per CONTEXT.md clean break decision").
- Blocks: Phase 3-4 integration testing; users cannot self-diagnose connection issues without firmware modification.
- Mitigation: Currently acceptable for embedded single-user device. If shipping to others, add optional compile-time debug mode (e.g., `#define DEBUG_ENABLED` to enable Serial.println() statements).

**No watchdog timer or heart-beat monitoring:**
- Problem: If firmware hangs in any function (e.g., deadlock in ripple animation millis() overflow, or infinite loop in Bounce2.update()), the controller becomes unresponsive but continues drawing USB power. Host DAW may lose MIDI sync without feedback.
- Blocks: Phase 4 beat chaser (which depends on millis() clock drift handling); critical for reliable production use.
- Mitigation: Teensy 3.5 has built-in watchdog timer. Not implemented yet; could be added in Phase 3-4 if needed. For now, manual testing with 4-hour runtime confirms no hangs.

**No MIDI input filtering or bounds checking:**
- Problem: Incoming CC, NoteOn, NoteOff, and Pitch Bend are processed without validation. If external MIDI source sends malformed messages or out-of-range values (e.g., CC 255, note 128), firmware behavior is undefined.
- Blocks: If controller is ever connected to untrusted MIDI sources, could crash firmware.
- Mitigation: Current design assumes Logic Pro as sole MIDI source (trusted). If multi-source MIDI is needed (Phase 4 beat chaser from external click track, for example), add input validation.

## Test Coverage Gaps

**No unit tests for core state machines:**
- What's not tested:
  - Fader pickup FSM (OUT_OF_SYNC → SYNCED transitions, deadband crossing, lazy blink reveal)
  - MCUButton blink FSM (blink period updates, phase toggling)
  - NoteRegistry and ButtonRegistry map operations
  - Ripple animation distance calculations and timing
- Files: `src/fader.cpp`, `src/mcuButton.cpp`, `src/noteRegistry.cpp`, `src/buttonRegistry.cpp`, `src/inputManager.cpp`
- Risk: If pickup FSM logic is changed or blink timing is adjusted, regressions could be introduced silently. No test suite catches them until hardware verification (manual, time-consuming).
- Priority: **High** — Phase 2 completion requires manual hardware verification of pickup mode; unit tests would accelerate Phase 3-4 development by 20-30%.

**No integration tests for MIDI message flow:**
- What's not tested:
  - Full NoteOn → NoteRegistry → MCUButton → LED update chain
  - Pitch bend message arrival → setFaderDawValue → Fader FSM → MIDI output
  - Multiple faders transitioning between SYNCED/OUT_OF_SYNC simultaneously (multi-bank switch scenario)
- Files: All of inputManager, fader, mcuButton in concert
- Risk: If refactoring any MIDI callback or registry lookup, side effects could break LED feedback without obvious cause.
- Priority: **Medium** — Phase 3 transport grid integration should include basic MIDI echo tests (send NoteOn, verify NoteRegistry lookup works).

**No hardware abstraction tests:**
- What's not tested:
  - ADC reading and noise filtering (Potentiometer.hasChanged threshold)
  - Button debounce timing (does Bounce2 actually debounce on this hardware pin configuration?)
  - SoftPWM fade timing (is 125ms fade time perceived correctly, or does SoftPWM timer interrupt jitter affect it?)
- Files: `src/potentiometer.cpp`, `src/mcuButton.cpp` (Bounce2 usage), `src/inputManager.cpp` (SoftPWM calls)
- Risk: Minor drift in timing could cause faders to feel unresponsive or blinks to strobe at wrong frequency.
- Priority: **Low** — These are verified through manual hardware testing already. Unit tests difficult without a Teensy and real pins; integration tests in Phase 3 can catch timing issues.

---

*Concerns audit: 2026-03-02*

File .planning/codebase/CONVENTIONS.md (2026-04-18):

# Coding Conventions

**Analysis Date:** 2026-03-02

## Naming Patterns

**Files:**
- Header files use `.h` extension (not `.hpp`)
- Implementation files use `.cpp` extension
- Names are lowercase with underscores for multi-word files: `inputManager.h`, `buttonRegistry.cpp`, `mcuButton.h`, `pinDefines.h`
- Pin/configuration constants use `pinDefines.h` pattern

**Functions:**
- Member functions: camelCase starting with lowercase: `init()`, `read()`, `setLedState()`, `handleControlChangeMessage()`
- Private helper functions: camelCase: `hasChanged()`, `ledStateToPWM()`, `triggerRipple()`
- Static functions: camelCase: `playStartupAnimation()`, `handleSysEx()`, `handleNoteOn()`
- Callback handlers: `handle[Event]` pattern: `handleSysEx()`, `handleNoteOn()`, `handleNoteOff()`, `handlePitchBend()`

**Variables:**
- Member variables: prefix with underscore `_variableName`: `_buttonPin`, `_ledPin`, `_ccNum`, `_debounceTime`, `_hasLed`, `_ripple`, `_selectedTrack`
- Local variables: camelCase without prefix: `ledState`, `value`, `distance`, `startMs`, `fader14bit`
- Constants: UPPERCASE_WITH_UNDERSCORES: `DEBOUNCE_TIME`, `NUM_GRID_BUTTONS`, `NUM_TRACKS`, `RETRY_INTERVAL_MS`, `LED_MAX_BRIGHTNESS`
- Static compile-time constants defined in headers: `const int NUM_GRID_BUTTONS = 16;`

**Types and Classes:**
- Class names: PascalCase: `Button`, `MCUButton`, `InputManager`, `Potentiometer`, `Fader`, `ButtonRegistry`, `NoteRegistry`, `MCUProtocol`
- Enum names: PascalCase: `PickupState` with UPPERCASE members: `SYNCED`, `OUT_OF_SYNC`
- Struct names: PascalCase: `RippleState`

## Code Style

**Formatting:**
- No automatic formatter detected (no .clang-format, .prettierrc, or eslint config)
- Brace style: Opening brace on same line (1TBS): `if (condition) {`
- Indentation: 4 spaces (observed in all files)
- Line length: Generally follows ~100 character soft limit (observed in comments and code)
- Constructor initialization lists: comma-first on new line when multiple parameters:
  ```cpp
  MCUButton::MCUButton(int buttonPin, int ledPin, int noteNum, int debounceTime)
      : _buttonPin(buttonPin), _ledPin(ledPin), _noteNum(noteNum),
        _debounceTime(debounceTime), _hasLed(ledPin >= 0)
  ```

**Linting:**
- No linter configuration found in repository
- No pre-commit hooks detected
- Manual code review drives style consistency

**Comments:**
- Inline comments use `// Comment` style
- Multi-line comments explained in context
- Block comments above functions explain purpose and parameters
- Design decision markers used: `BOOT-01:`, `PICK-01:`, `MCU-04:`, `MCU-06:` etc. prefix complex sections

## Import Organization

**Order:**
1. Standard/system libraries: `#include <Arduino.h>`, `#include <SoftPWM.h>`, `#include <Bounce2.h>`, `#include <MIDIUSB.h>`
2. Standard C++ libraries: `#include <map>`, `#include <vector>`
3. Local project headers: `#include "pinDefines.h"`, `#include "inputManager.h"`

**Path Aliases:**
- No path aliases detected (not using `#define` or CMake ALIAS patterns)
- Direct relative includes from `src/` directory: `#include "button.h"`

**Header Guards:**
- Format: `#ifndef filename_h` / `#define filename_h` / `#endif`
- Examples: `button_h`, `pin_defines`, `mcu_button_h`, `button_manager` (note: `button_manager` used in `inputManager.h` not standard naming)

## Error Handling

**Patterns:**
- No exceptions (Arduino/embedded C++ best practice — exceptions disabled)
- Sentinel value pattern: `-1` indicates uninitialized/unconfigured state
  - `MCUButton` constructor: `_buttonPin(-1)` signals unused button
  - `Fader`: `_lastFader14bit(-1)` means first read
  - `Potentiometer`: `lastReading = -1` skips first-read send
- Early returns to skip invalid operations:
  ```cpp
  if (_buttonPin < 0) return;  // skip if not configured
  if (!_hasLed) return;        // skip if no LED hardware
  ```
- Range validation with `constrain()` for MIDI values:
  ```cpp
  int absSteps = constrain(abs(steps), 1, 63);  // enforce 1-63 range
  ```
- Ternary operators for conditional assignments:
  ```cpp
  uint8_t msg = (steps > 0) ? (uint8_t)absSteps : (uint8_t)(absSteps | 0x40);
  ```

## Logging

**Framework:** Serial via Arduino `Serial.println()` (commented out in production code)

**Patterns:**
- Debug prints exist but are commented: `// Serial.println("ROSE");` in `button.cpp` line 31
- No active logging in deployed code
- No structured logging or debug levels
- Startup sequence prints expected to be added for handshake debugging if needed

## Comments and Documentation

**When to Comment:**
- Above complex algorithms explaining intent: see `playStartupAnimation()` explaining LED wave sweep in main.cpp
- Explaining non-obvious MIDI behavior:
  ```cpp
  // MCU VPot sign-magnitude relative format (Logic Pro / Mackie Control):
  //   CW:  0x01-0x3F (bit 6 = 0, bits 0-5 = speed 1-63)
  //   CCW: 0x41-0x7F (bit 6 = 1, bits 0-5 = speed 1-63)
  ```
- Documenting pickup/bank-switch thresholds with rationale: `FADER_NOISE_THRESHOLD = 48` comment explains "proportionally equivalent to ANALOG_NOISE=3 on 0-1023 ADC"
- Decision markers linking to design docs: `BOOT-01:`, `PICK-05:`, `MCU-04:` prefix sections

**JSDoc/TSDoc:**
- Not used (embedded C++ with Arduino framework, not TypeScript)
- No formal doc generation tools observed

## Function Design

**Size:**
- Functions generally 10-50 lines
- Complex initialization split into `setup()` (configure) + `init()` (hardware init) pattern
- Example: `MCUButton::setup()` (5 lines, store params), `MCUButton::init()` (10 lines, hardware setup)

**Parameters:**
- Constructor pattern uses member initializer lists: `Button(int buttonPin, int ledPin, int ccNum, int debounceTime)`
- Two-phase construction: default constructor + `setup()` call for arrays
  ```cpp
  MCUButton gridButtons[NUM_GRID_BUTTONS];  // default construct
  gridButtons[0].setup(K1_SW, LED_K1, MCU_NOTE_BANK_LEFT, DEBOUNCE_TIME);  // configure
  ```
- No pointer parameters except for owned objects like `MCUButton* btn` passed to `setChannelButton()`

**Return Values:**
- `bool` for state queries and change detection: `hasChanged()`, `read()`, `poll()`, `isBlinking()`
- `int` for pin/index lookups: `getLEDPin()`, `getNoteNum()`
- `void` for state mutations: `setLedState()`, `startBlink()`, `stopBlink()`
- Sentinel values on failure: `lastReading = -1` means uninitialized

## Module Design

**Exports:**
- Public interface in `.h` files defines API
- Private members in `.h` files hide implementation details:
  ```cpp
  public:
      void init();
      void read();
  private:
      int _buttonPin;
      Bounce _bounce;
  ```
- Extern singletons at file scope: `extern MCUProtocol mcuProtocol;` in `mcuProtocol.h`

**Barrel Files:**
- Not used (not a TypeScript/JavaScript codebase)
- Each `.h` is self-contained; no central export aggregation

## Array and State Management

**Arrays:**
- Fixed-size arrays for hardware inputs: `MCUButton gridButtons[NUM_GRID_BUTTONS];`
- Parallel arrays for spatial data:
  ```cpp
  float dist[24];           // Euclidean distance
  uint8_t brightness[24];   // pre-computed dampened brightness
  bool lit[24];             // has this LED been turned on yet?
  ```
- Maps for sparse lookups: `std::map<uint8_t, MCUButton*> noteToButton;` in `NoteRegistry`

**State Machines:**
- Simple enum-based state: `PickupState { SYNCED, OUT_OF_SYNC };`
- Blink state tracked with `bool _blinking` + `uint32_t _lastBlinkMs` + `bool _blinkPhase`
- Ripple animation state in struct:
  ```cpp
  struct RippleState {
      bool active;
      uint32_t startMs;
      float dist[24];
      // ...
  } _ripple;
  ```

---

*Convention analysis: 2026-03-02*

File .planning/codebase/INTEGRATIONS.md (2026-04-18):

# External Integrations

**Analysis Date:** 2026-03-02

## APIs & External Services

**MIDI Protocol:**
- USB MIDI over native Teensy USB endpoint
  - SDK/Client: Teensyduino `usbMIDI` object (built-in to Arduino framework)
  - Channel: MIDI channel 1 (all messages)
  - Protocol: Standard USB MIDI class-compliant device
  - No authentication required

**Mackie Control Universal (MCU) Protocol:**
- Handshake via SysEx (System Exclusive)
  - Header: F0 00 00 66 14 (Mackie MCU device ID)
  - Device Identity: "PHAEDR\0" (7-byte serial)
  - Handshake: Challenge-response authentication (4-byte static challenge: 0x7A 0x6B 0x5C 0x4D)
  - Implementation: `src/mcuProtocol.h/cpp`
  - Status: Required for handshake before input/output; retry every 5 seconds if DAW doesn't respond

## Data Storage

**Databases:**
- Not applicable

**File Storage:**
- Local firmware only; no persistent storage beyond microcontroller flash

**Caching:**
- Not applicable (real-time control surface, no network I/O)

## Authentication & Identity

**Auth Provider:**
- Custom MCU Protocol challenge-response
  - Implementation: `src/mcuProtocol.cpp` - validateChallengeResponse()
  - Device identity hardcoded: "PHAEDR\0"
  - Challenge bytes: static (0x7A, 0x6B, 0x5C, 0x4D)
  - No user login; DAW (Logic Pro, Ableton, etc.) responds to handshake

## Monitoring & Observability

**Error Tracking:**
- None configured

**Logs:**
- Serial debug output (optional, enabled via `-DUSB_MIDI_SERIAL` build flag)
  - Monitor with: `pio device monitor`
  - No persistent logging

## CI/CD & Deployment

**Hosting:**
- Embedded firmware (Teensy 3.5 microcontroller) — no cloud deployment
- Local build and upload via USB cable

**CI Pipeline:**
- None configured

**Upload:**
- `pio run --target upload` triggers Teensy bootloader automatically

## Environment Configuration

**Required env vars:**
- None

**Secrets location:**
- No secrets; MCU challenge bytes are static and hardcoded in firmware

## Webhooks & Callbacks

**Incoming:**
- MIDI Note On/Off (from DAW/Logic Pro)
  - Handler: `handleNoteOn()`, `handleNoteOff()` in `src/main.cpp`
  - Routes to: `InputManager.handleNoteMessage()` → `NoteRegistry` → LED state updates
  - Use case: DAW sends note on/off to update button LEDs based on transport/track state

- MIDI Pitch Bend (from DAW/Logic Pro, channels 1-8)
  - Handler: `handlePitchBend()` in `src/main.cpp`
  - Routes to: `InputManager.setFaderDawValue()` → Fader pickup mode
  - Use case: DAW sends fader position feedback (14-bit value) for pickup detection and bank switching
  - Range: Channels 1-8 map to fader 1-8; value +8192 offset to -8192..+8191 signed range

- MIDI SysEx (System Exclusive)
  - Handler: `handleSysEx()` in `src/main.cpp`
  - Routes to: `MCUProtocol.handleSysEx()` → handshake authentication
  - Use case: DAW responds to MCU protocol handshake query

**Outgoing:**
- MIDI CC (Control Change)
  - Sent on button/knob/slider change
  - Grid buttons: CC 102-117 (velocity 127 = pressed, 0 = released)
  - Track buttons: MIDI Note On/Off (notes 0-7 = Arm, 8-15 = Solo, 16-23 = Mute, 46-47 = Bank navigation)
  - Knobs: CC 16-23 (relative VPot encoder format: 0x01 = CCW -1 step, 0x41 = CW +1 step)
  - Sliders (Faders): MIDI Pitch Bend on channels 1-8 (14-bit value 0-16383)

- MIDI SysEx (System Exclusive)
  - Sent during handshake: unsolicited query to DAW to initiate authentication
  - Message format: F0 00 00 66 14 [identity] [challenge] F7
  - Retry: Every 5 seconds if no response, until handshake completes

## MIDI CC Mapping Reference

**Input → DAW (Controller sends):**

| Type | Count | MIDI Channel | Values/Format | Notes |
|---|---|---|---|---|
| Grid buttons | 16 | 1 | CC 102-117 (vel 127/0) | Button press/release |
| Track buttons (Arm) | 8 | 1 | Note 0-7 (vel 127/0) | MCU protocol: note on = armed |
| Track buttons (Solo) | 8 | 1 | Note 8-15 (vel 127/0) | MCU protocol |
| Track buttons (Mute) | 8 | 1 | Note 16-23 (vel 127/0) | MCU protocol |
| Bank Left | 1 | 1 | Note 46 (vel 127) | Bank shift << |
| Bank Right | 1 | 1 | Note 47 (vel 127) | Bank shift >> |
| Knobs (VPot) | 8 | 1 | CC 16-23 (rel: 0x01=CCW, 0x41=CW) | Relative encoder format |
| Sliders (Faders) | 8 | 1-8 | Pitch Bend (14-bit 0-16383) | Channel = fader index + 1 |

**Output ← DAW (DAW sends to update LEDs):**

| Type | MIDI Type | Channel | Values | Notes |
|---|---|---|---|---|
| Grid button LEDs | Note On | 1 | Notes (various) | Velocity: 127=on, 0=off, 1=blink (Phase 2) |
| Track button LEDs | Note On | 1 | Notes (various) | Velocity: 127=on, 0=off |
| Fader feedback | Pitch Bend | 1-8 | 14-bit 0-16383 | Channel = fader index + 1; triggers pickup mode |

## Hardware Interfaces

**GPIO (General Purpose I/O):**
- 24 digital input pins: button switches (16 grid + 8 track buttons)
  - Pin assignments: `src/pinDefines.h` (K1_SW-K16_SW, P1_SW-P8_SW)
  - Debounce: 20ms (via Bounce2 library)

- 24 digital output pins: LED drivers (16 grid + 8 track LEDs)
  - Pin assignments: `src/pinDefines.h` (LED_K1-LED_K16, LED_P1-LED_P8)
  - Control: SoftPWM with brightness 0-180 (180/255 = 70.6% duty cycle for power budget)
  - Fade support: SoftPWM allows gradual brightness transitions

**ADC (Analog-to-Digital Converter):**
- 8 knob analog inputs (10-bit resolution, 0-1023 ADC units)
  - Pin assignments: `src/pinDefines.h` (KNOB_1-KNOB_8: pins 15-19, A10-A12)
  - Noise threshold: 3 ADC units (±1.5 units tolerance)
  - Relative encoder tuning: ADC_PER_STEP = 8 (1023 / 8 ≈ 128 steps per full sweep)

- 8 slider analog inputs (10-bit resolution, 0-1023 ADC units)
  - Pin assignments: `src/pinDefines.h` (SLIDE_1-SLIDE_8: pins A13-A15, A20-A22, A0, A6)
  - Noise threshold: 48 ADC units (proportional to 3-unit knob threshold, mapped to 14-bit MIDI range 0-16383)
  - Pickup mode: Detects bank switches (>1024 unit gap between physical and DAW position)

---

*Integration audit: 2026-03-02*

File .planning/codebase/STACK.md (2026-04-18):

# Technology Stack

**Analysis Date:** 2026-03-02

## Languages

**Primary:**
- C++ (Arduino dialect) - All firmware code (src/*.cpp and src/*.h)

**Secondary:**
- Arduino Sketch - Arduino-style setup()/loop() pattern in `src/main.cpp`

## Runtime

**Environment:**
- Teensyduino (Arduino framework for Teensy microcontrollers)
- Teensy 3.5 ARM Cortex-M4 @ 120 MHz
- Flash: 512 KB, RAM: 192 KB

**Package Manager:**
- PlatformIO (pio CLI)
- Lockfile: `platformio.lock` (managed automatically by PlatformIO)

## Frameworks

**Core:**
- Arduino Framework (via PlatformIO/Teensyduino) - Microcontroller programming model with setup()/loop()
- Teensyduino USB Stack - Native USB MIDI and Serial support via `usbMIDI` object

**Input/Output:**
- Bounce2 2.70 - Button debouncing with configurable debounce time
- SoftPWM 1.0.1 (vendored locally) - PWM-based LED brightness/fading control

**Build/Dev:**
- PlatformIO - Build system and uploader
- platformio.ini - Project configuration

## Key Dependencies

**Critical:**
- `Bounce2` (^2.70) - Debounces 24 button inputs (16 grid + 8 track). Required for stable button reads. Installation: `thomasfredericks/Bounce2@^2.70`
- `SoftPWM` (1.0.1) - Drives 24 LED outputs (22 channels: K1-K16 grid LEDs + P1-P8 track LEDs) with PWM fading. Vendored locally in `lib/SoftPWM/` with custom compile flag `SOFTPWM_MAXCHANNELS=22` (increased from upstream default of 20).

**Infrastructure:**
- Teensyduino USB MIDI Stack (built into Arduino framework) - USB MIDI endpoint + optional serial debug

## Configuration

**Environment:**
- No .env files
- No external configuration required
- Build flag: `-DUSB_MIDI_SERIAL` (platformio.ini line 20) enables simultaneous USB MIDI + serial debug output

**Build:**
- `platformio.ini` - Single environment: `[env:teensy35]`
  - platform: teensy
  - board: teensy35
  - framework: arduino
  - lib_deps: Bounce2, SoftPWM (vendored)
  - build_flags: `-DUSB_MIDI_SERIAL`

**Hardware Configuration:**
- GPIO pin mappings: `src/pinDefines.h` (24 button pins + 24 LED pins + 8 knob ADC pins + 8 slider ADC pins)
- LED brightness limit: `LED_MAX_BRIGHTNESS = 180` (70.6% PWM duty to stay within 500mA USB power budget)

## Platform Requirements

**Development:**
- PlatformIO installed: `pip install platformio`
- USB cable to Teensy 3.5
- Optional: PlatformIO IDE extension for VS Code / alternative IDE support

**Production:**
- Teensy 3.5 microcontroller board
- Custom PCB with:
  - 16 grid buttons + 16 LEDs
  - 8 track buttons + 8 LEDs
  - 8 rotary potentiometer knobs (analog inputs)
  - 8 linear faders (analog inputs)
- USB host with USB MIDI driver support (DAW such as Ableton Live, Logic Pro, etc.)
- USB power: ~489 mA max (24 LEDs × 14.1 mA avg + 150 mA Teensy = ~489 mA)

---

*Stack analysis: 2026-03-02*

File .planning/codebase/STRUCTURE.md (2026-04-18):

# Codebase Structure

**Analysis Date:** 2026-03-02

## Directory Layout

```
phaedr-midi-controller/
├── src/                    # Main firmware source (Arduino C++)
├── lib/                    # Vendored libraries
├── include/                # Project-wide headers
├── test/                   # Test suite (PlatformIO)
├── assets/                 # Hardware (STL files, schematics)
├── .planning/              # GSD planning docs and phases
├── platformio.ini          # Build config
├── CLAUDE.md               # Project context (this file references it)
└── README.md               # Overview
```

## Directory Purposes

**src/ — Firmware Implementation:**
- Purpose: All firmware source code (entry point, device drivers, protocol, orchestration)
- Contains: `.h` headers and `.cpp` implementations
- Key files: `main.cpp` (entry point), `inputManager.cpp` (orchestrator), device drivers

**lib/SoftPWM/ — PWM Library:**
- Purpose: Vendored SoftPWM library for LED fading (not in package manager)
- Contains: `SoftPWM.h/cpp`, `SoftPWM_timer.h`
- Key files: `SoftPWM.h` — provides `SoftPWMSet(pin, brightness)` and `SoftPWMSetFadeTime()`
- Committed: Yes (vendored, critical dependency)

**include/ — Arduino Headers:**
- Purpose: Teensyduino and standard library includes (empty after git clone)
- Committed: No (generated during build)

**test/ — Test Suite:**
- Purpose: Unit tests for firmware (PlatformIO test framework)
- Key files: Likely empty or minimal (project is hardware-first)
- Committed: Present but see latest commits

**assets/STLs/ — Hardware Design:**
- Purpose: 3D models for enclosure/mounting
- Committed: Yes (hardware design artifacts)

**.planning/codebase/ — This Directory:**
- Purpose: Analyzed architecture/structure/conventions/testing docs
- Generated by: GSD map-codebase commands
- Committed: Yes (shared codebase knowledge)

**.planning/phases/ — Implementation Phases:**
- Purpose: GSD phase breakdowns, tasks, and summaries
- Generated by: GSD plan-phase and execute-phase commands
- Committed: Yes (shared work tracking)

**.planning/research/ — Technical Research:**
- Purpose: External API docs, protocol findings, decision logs
- Committed: Yes (shared knowledge base)

## Key File Locations

**Entry Points:**
- `src/main.cpp`: Firmware entry point — `setup()` and `loop()`

**Core Orchestrator:**
- `src/inputManager.h/cpp`: Central dispatcher for all inputs, manages NoteRegistry, ripple animation, track selection

**Hardware Abstraction (Input Devices):**
- `src/button.h/cpp`: Legacy button class (deprecating; MCUButton is preferred)
- `src/mcuButton.h/cpp`: MCU protocol button with LED control and blink FSM
- `src/potentiometer.h/cpp`: Analog input (knobs, sliders) with absolute/relative modes
- `src/fader.h/cpp`: Pitch bend fader with pickup mode and bank switch detection

**Protocol & Feedback:**
- `src/mcuProtocol.h/cpp`: MCU SysEx handshake state machine
- `src/noteRegistry.h/cpp`: Maps incoming note numbers to buttons for LED feedback
- `src/mcuConfig.h`: MCU note number constants and mode button definitions

**Configuration & Pinouts:**
- `src/pinDefines.h`: Hardware pin assignments (switches, LEDs, analog inputs)

## Naming Conventions

**Files:**
- Lowercase with camelCase: `inputManager.h`, `mcuButton.cpp`
- One class per `.h`/`.cpp` pair (with few exceptions)
- Header guards: `#ifndef class_name` (lowercase with underscores)

**Classes:**
- PascalCase: `InputManager`, `MCUButton`, `Potentiometer`, `MCUProtocol`, `NoteRegistry`
- MCU-related classes prefixed with `MCU`: `MCUButton`, `MCUProtocol`, `mcuConfig.h`

**Functions & Methods:**
- camelCase: `readAll()`, `handleNoteMessage()`, `setLedState()`, `isHandshakeComplete()`
- Private methods prefixed with underscore: `_triggerRipple()`, `_setDawValue()` (not consistently applied)
- Getters with `get`: `getButton()`, `getLedPin()`
- State queries without prefix: `isHandshakeComplete()`, `isBlinking()`

**Variables & Constants:**
- Local variables: camelCase: `fader14bit`, `originIdx`, `blinkPeriod`
- Member variables: underscore prefix: `_buttonPin`, `_ledPin`, `_noteNum`, `_pickupState`
- Static constants: UPPER_SNAKE_CASE: `DEBOUNCE_TIME`, `NUM_GRID_BUTTONS`, `MCU_HEADER`
- MIDI config constants: `MCU_NOTE_*` or `MIDI_CH_*`

**Structures & Enums:**
- PascalCase: `RippleState` (struct), `PickupState` (enum)
- Enum values: UPPER_SNAKE_CASE: `SYNCED`, `OUT_OF_SYNC`

## Where to Add New Code

**New Button (Grid or Track):**
- Define pin in `src/pinDefines.h`
- Add `MCUButton` instance to appropriate array in `src/inputManager.h`
- Call `setup()` in `InputManager::init()` (`src/inputManager.cpp:8-92`)
- If LED feedback: register note in `NoteRegistry::registerButton()` call

**New Knob or Slider:**
- Define ADC pin in `src/pinDefines.h`
- Add `Potentiometer` instance to `src/inputManager.h` (outside class) or as member array
- Initialize in `InputManager::init()`
- Call `read()` in `InputManager::readAll()` (`src/inputManager.cpp:190-212`)

**New MCU Protocol Feature:**
- Add SysEx message type constant to `src/mcuProtocol.h`
- Extend `handleSysEx()` in `src/mcuProtocol.cpp` with new message case
- Add helper method for sending new message type
- Register with `usbMIDI.setHandle*()` in `main.cpp:setup()`

**New MIDI Handler:**
- Add callback function in `src/main.cpp` (e.g., `handleControlChange()`)
- Register with `usbMIDI.setHandle*(callback)` in `setup()`
- Route to appropriate InputManager or MCUProtocol method

**New Animation or LED Effect:**
- Add state struct similar to `RippleState` in `InputManager` private section
- Add trigger method (e.g., `triggerEffect()`)
- Add update method (e.g., `updateEffect()`)
- Call from `loop()` at appropriate point

**New Utility or Helper:**
- If device-specific: add to corresponding driver class (`src/button.cpp`, `src/mcuButton.cpp`, etc.)
- If cross-device: add to `InputManager`
- Avoid creating new files unless it's a distinct device class or protocol module

## Special Directories

**lib/ — Vendored Dependencies:**
- Purpose: Libraries not available via PlatformIO package manager
- Generated: No (pre-added to repo)
- Committed: Yes (must include SoftPWM for PWM control)
- Contains: Only `SoftPWM/` currently

**.pio/ — Build Artifacts:**
- Purpose: PlatformIO build cache, dependency downloads, compiled objects
- Generated: Yes (during `pio run`)
- Committed: No (in .gitignore)
- Do NOT edit: automated by PlatformIO

**include/ — Teensyduino Headers:**
- Purpose: Copied from Teensyduino SDK during build
- Generated: Yes
- Committed: No
- Do NOT edit: regenerated on every build

**test/ — PlatformIO Test Framework:**
- Purpose: Native or on-device testing (if used)
- Pattern: One `.cpp` per test suite, mirrors `src/` structure
- Committed: Present but likely empty
- To run: `pio test`

**.planning/ — GSD-Generated Planning:**
- Purpose: Codebase analysis (this file), phase breakdowns, research notes
- Generated: By GSD commands (/gsd:map-codebase, /gsd:plan-phase, /gsd:execute-phase)
- Committed: Yes (shared work artifacts)
- Do NOT edit manually: regenerated by orchestrator on phase completion

## Build Configuration

**platformio.ini — Platform I/O Configuration:**
- Target environment: `teensy35`
- Arduino framework
- Build flags: `-DUSB_MIDI_SERIAL` (enables USB MIDI + Serial simultaneously)
- Dependencies: `Bounce2` (button debouncing), `SoftPWM` (LED PWM fading)

**Key Settings:**
```ini
[env:teensy35]
platform = teensy
board = teensy35
framework = arduino
lib_deps =
    Bounce2@^2.70
    SoftPWM@^1.0.1
build_flags = -DUSB_MIDI_SERIAL
```

---

*Structure analysis: 2026-03-02*

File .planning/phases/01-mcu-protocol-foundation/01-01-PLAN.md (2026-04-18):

---
phase: 01-mcu-protocol-foundation
plan: "01"
type: execute
wave: 1
depends_on: []
files_modified:
  - src/inputManager.cpp
  - src/main.cpp
autonomous: true
requirements:
  - FIX-01
  - FIX-02

must_haves:
  truths:
    - "DAW-driven setLedState() calls reach the physical Button object (not a stack copy)"
    - "No Serial.println calls execute inside any usbMIDI callback"
    - "Firmware compiles clean after both fixes"
  artifacts:
    - path: "src/inputManager.cpp"
      provides: "Fixed handleControlChangeMessage using Button* pointer"
      contains: "Button* button = buttonRegistry.ccNumToButton"
    - path: "src/main.cpp"
      provides: "MIDI callbacks free of Serial output"
      contains: "void handleControlChangeMessage"
  key_links:
    - from: "src/inputManager.cpp"
      to: "Button::setLedState"
      via: "pointer dereference button->setLedState()"
      pattern: "button->setLedState"
    - from: "src/main.cpp"
      to: "usbMIDI callbacks"
      via: "no Serial.println present"
      pattern: "void handleClock"
---

<objective>
Fix two pre-existing bugs that block all subsequent MCU work: the copy-by-value Button dereference that silently discards DAW-driven LED updates (FIX-01), and the Serial.println calls inside usbMIDI callbacks that cause timing jitter at 24 PPQN clock rates (FIX-02).

Purpose: These fixes are gates. FIX-01 means no DAW-driven LED can ever work until it's fixed. FIX-02 means MIDI clock timing is unreliable with any Serial output in callbacks.
Output: A compilable firmware with both bugs eliminated, ready for MCU protocol work to be layered on top.
</objective>

<execution_context>
@/Users/kenmarut/.claude/get-shit-done/workflows/execute-plan.md
@/Users/kenmarut/.claude/get-shit-done/templates/summary.md
</execution_context>

<context>
@.planning/PROJECT.md
@.planning/ROADMAP.md
@.planning/STATE.md
@src/inputManager.cpp
@src/inputManager.h
@src/main.cpp
@src/button.h
@src/buttonRegistry.h
</context>

<tasks>

<task type="auto">
  <name>Task 1: Fix FIX-01 — pointer dereference in handleControlChangeMessage</name>
  <files>src/inputManager.cpp</files>
  <action>
In `src/inputManager.cpp`, the `handleControlChangeMessage` method at line 25 contains:

```cpp
Button button = *(buttonRegistry.ccNumToButton[ccNum]);
button.setLedState(velocity == 127 ? HIGH : LOW);
```

This creates a temporary stack copy of the Button object. Calling `setLedState()` on the copy updates the copy's internal state but not the original object in the `gridButtons[]` or `trackButtons[]` arrays. The physical LED never changes.

Fix by using a pointer instead:

```cpp
void InputManager::handleControlChangeMessage(byte channel, byte ccNum, byte velocity)
{
    if (channel == 1)
    {
        if ((ccNum >= 102 && ccNum <= 117) || (ccNum >= 20 && ccNum <= 27))
        {
            Button* button = buttonRegistry.ccNumToButton[ccNum];
            if (button != nullptr) {
                button->setLedState(velocity == 127 ? HIGH : LOW);
            }
        }
    }
}
```

The null check guards against a missing CC number in the registry (defensive; should not happen in practice).
  </action>
  <verify>Run `pio run` from the repo root. Confirm the build succeeds with no errors on `inputManager.cpp`.</verify>
  <done>Build passes. `src/inputManager.cpp` contains `Button* button = buttonRegistry.ccNumToButton[ccNum]` and `button->setLedState(...)`. No copy-by-value dereference remains.</done>
</task>

<task type="auto">
  <name>Task 2: Fix FIX-02 — remove Serial.println from all usbMIDI callbacks</name>
  <files>src/main.cpp</files>
  <action>
In `src/main.cpp`, the following Serial output calls must be removed from usbMIDI callback functions. At 120 BPM, `handleClock()` fires 48 times/second; a single `Serial.println` per call can stall processing by 1-10ms, causing missed clock pulses.

Remove these lines:
- Line 29: `Serial.println("CONTROL CHANGE");` in `handleControlChangeMessage()`
- Line 35: `Serial.println("HANDLE START");` in `handleStart()`
- Line 40: `Serial.println("HANDLE CLOCK");` in `handleClock()`

The `handleStop()` function already has its println commented out — leave it as-is.

After removal, the callbacks should be lean:

```cpp
void handleControlChangeMessage(byte channel, byte ccNum, byte velocity)
{
    inputManager.handleControlChangeMessage(channel, ccNum, velocity);
}

void handleStart()
{
}

void handleClock()
{
}

void handleStop()
{
    // Serial.println("HANDLE STOP");
}
```

Do NOT add a `#define DEBUG` guard system — simply delete the lines. If debug output is needed in the future, it can be added then. Per user decision (CONTEXT.md "clean break"), no legacy compatibility shims.
  </action>
  <verify>Run `pio run` from the repo root. Confirm build succeeds. Grep `src/main.cpp` to confirm no `Serial.println` calls remain in callback functions: `grep -n "Serial.println" src/main.cpp` should return no results in `handleControlChangeMessage`, `handleStart`, or `handleClock`.</verify>
  <done>Build passes. No Serial.println calls exist inside any usbMIDI callback in `src/main.cpp`.</done>
</task>

</tasks>

<verification>
From repo root:
1. `pio run` — build must succeed with zero errors
2. `grep -n "Serial.println" /Users/kenmarut/repo/phaedr-midi-controller/src/main.cpp` — must show no results in callback bodies (handleControlChangeMessage, handleStart, handleClock)
3. `grep -n "Button button = " /Users/kenmarut/repo/phaedr-midi-controller/src/inputManager.cpp` — must return no results (copy-by-value pattern eliminated)
4. `grep -n "Button\* button" /Users/kenmarut/repo/phaedr-midi-controller/src/inputManager.cpp` — must show the pointer fix
</verification>

<success_criteria>
- `pio run` exits 0 with no errors
- `handleControlChangeMessage` in `inputManager.cpp` uses `Button*` (pointer), not `Button` (copy)
- No `Serial.println` calls inside `handleControlChangeMessage`, `handleStart`, or `handleClock` in `main.cpp`
- Both bugs confirmed eliminated before any MCU protocol work begins
</success_criteria>

<output>
After completion, create `.planning/phases/01-mcu-protocol-foundation/01-01-SUMMARY.md`
</output>

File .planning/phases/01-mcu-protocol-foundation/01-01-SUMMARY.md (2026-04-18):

---
phase: 01-mcu-protocol-foundation
plan: "01"
subsystem: firmware
tags: [teensy, arduino, platformio, usb-midi, cpp, led-control]

# Dependency graph
requires: []
provides:
  - "DAW-driven LED updates via Button* pointer (FIX-01)"
  - "Jitter-free MIDI clock callbacks with no Serial output (FIX-02)"
  - "Clean-building firmware gate for MCU protocol work"
affects:
  - 01-mcu-protocol-foundation
  - all subsequent phases that rely on LED feedback

# Tech tracking
tech-stack:
  added: []
  patterns:
    - "Button registry uses Button* pointers — always dereference via pointer, never copy-by-value"
    - "usbMIDI callbacks must be lean — no Serial, no blocking ops at 48Hz clock rate"

key-files:
  created: []
  modified:
    - src/inputManager.cpp
    - src/main.cpp

key-decisions:
  - "No DEBUG guard system — Serial.println lines deleted outright per clean-break decision"
  - "Null check added to handleControlChangeMessage for defensive safety (guards missing CC in registry)"

patterns-established:
  - "Button pointer pattern: Button* button = buttonRegistry.ccNumToButton[ccNum]; if (button != nullptr) { button->setLedState(...); }"
  - "Callback hygiene: usbMIDI callbacks delegate immediately, no inline logic or I/O"

requirements-completed: [FIX-01, FIX-02]

# Metrics
duration: 2min
completed: 2026-02-21
---

# Phase 1 Plan 01: Bug Fixes — FIX-01 and FIX-02 Summary

**Fixed copy-by-value Button dereference (FIX-01) and Serial.println jitter in usbMIDI callbacks (FIX-02), unblocking all DAW-driven LED feedback and reliable MIDI clock handling**

## Performance

- **Duration:** ~2 min
- **Started:** 2026-02-22T03:39:18Z
- **Completed:** 2026-02-22T03:40:22Z
- **Tasks:** 2
- **Files modified:** 2

## Accomplishments

- FIX-01: Replaced stack-copy Button dereference with `Button*` pointer in `InputManager::handleControlChangeMessage`, so `setLedState()` now mutates the actual Button object stored in `gridButtons[]`/`trackButtons[]` rather than a temporary copy
- FIX-02: Deleted three `Serial.println` calls from `handleControlChangeMessage`, `handleStart`, and `handleClock` — eliminating 1–10ms stalls that caused dropped clock pulses at 24 PPQN (48 fires/sec at 120 BPM)
- Firmware builds clean (`SUCCESS`) with Flash usage slightly reduced (20264 → 18944 bytes) from removing string literals

## Task Commits

Each task was committed atomically:

1. **Task 1: Fix FIX-01 — pointer dereference in handleControlChangeMessage** - `e429788` (fix)
2. **Task 2: Fix FIX-02 — remove Serial.println from all usbMIDI callbacks** - `35d03cb` (fix)

## Files Created/Modified

- `src/inputManager.cpp` - handleControlChangeMessage now uses `Button*` pointer with null guard
- `src/main.cpp` - Three Serial.println calls removed from usbMIDI callback functions

## Decisions Made

- No `#define DEBUG` guard system added — Serial.println lines deleted outright. Per plan's explicit instruction ("Per user decision, clean break; no legacy compatibility shims"). If debug output is needed in future it can be added then.
- Added null guard (`if (button != nullptr)`) before `button->setLedState()` — defensive safety for any future CC number that might not be in the registry.

## Deviations from Plan

None - plan executed exactly as written.

## Issues Encountered

None — both fixes were straightforward. The `pio` CLI required the full path `/Users/kenmarut/.platformio/penv/bin/pio` since `pio` was not on the shell PATH, but this did not impact any source changes.

## User Setup Required

None - no external service configuration required.

## Next Phase Readiness

- Both critical gate bugs are eliminated — DAW-driven LED feedback is now architecturally correct
- Firmware compiles clean and is ready for MCU protocol work (SysEx handshake, transport note handling, fader pitch-bend math) to be layered on top
- No blockers introduced; pre-existing concern about MCU SysEx handshake byte sequence verification against real Logic Pro behavior remains open from STATE.md

---
*Phase: 01-mcu-protocol-foundation*
*Completed: 2026-02-22*

## Self-Check: PASSED

- FOUND: src/inputManager.cpp (modified)
- FOUND: src/main.cpp (modified)
- FOUND: .planning/phases/01-mcu-protocol-foundation/01-01-SUMMARY.md (created)
- FOUND: e429788 (Task 1 commit)
- FOUND: 35d03cb (Task 2 commit)
- FOUND: Button* pointer pattern in inputManager.cpp
- Serial.println count in main.cpp: 1 (commented-out line in handleStop — intentional per plan)

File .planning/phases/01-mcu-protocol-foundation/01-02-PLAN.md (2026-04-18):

---
phase: 01-mcu-protocol-foundation
plan: "02"
type: execute
wave: 1
depends_on: []
files_modified:
  - src/pinDefines.h
  - src/mcuButton.h
  - src/mcuButton.cpp
  - src/noteRegistry.h
  - src/noteRegistry.cpp
autonomous: true
requirements:
  - MCU-03
  - MCU-04
  - LED-01
  - LED-02
  - LED-04
  - PWR-01

must_haves:
  truths:
    - "MCUButton sends Note On (vel 127) then immediate Note Off (vel 0) on button press — no CC output"
    - "MCUButton does NOT toggle LED state on press — LED only changes via setLedState()"
    - "NoteRegistry maps note numbers to MCUButton* pointers via std::map"
    - "setLedState(127) sets LED to LED_MAX_BRIGHTNESS (not 255), setLedState(0) turns LED off via SoftPWM"
    - "LED_MAX_BRIGHTNESS constant (default 180) is defined in pinDefines.h and used in MCUButton::setLedState"
  artifacts:
    - path: "src/mcuButton.h"
      provides: "MCUButton class declaration"
      contains: "class MCUButton"
    - path: "src/mcuButton.cpp"
      provides: "MCUButton implementation — Note Bang + LED control"
      contains: "usbMIDI.sendNoteOn"
    - path: "src/noteRegistry.h"
      provides: "NoteRegistry class — note-to-MCUButton* map"
      contains: "class NoteRegistry"
    - path: "src/noteRegistry.cpp"
      provides: "NoteRegistry implementation"
      contains: "noteToButton"
  key_links:
    - from: "src/noteRegistry.h"
      to: "src/mcuButton.h"
      via: "MCUButton* pointer in map"
      pattern: "std::map.*MCUButton\\*"
    - from: "src/mcuButton.cpp"
      to: "SoftPWM"
      via: "SoftPWMSet in setLedState"
      pattern: "SoftPWMSet"
---

<objective>
Create the MCUButton class (replaces Button for channel strip and transport buttons) and the NoteRegistry class (replaces CC-to-Button map with note-to-MCUButton map). These are the core input and LED feedback components for the MCU protocol.

Purpose: MCUButton implements "wait for Logic" LED behavior — it sends a Note Bang on press but never self-toggles the LED. NoteRegistry enables incoming Note On/Off from Logic to reach the correct hardware LED via the note number.
Output: Four new source files: mcuButton.h, mcuButton.cpp, noteRegistry.h, noteRegistry.cpp
</objective>

<execution_context>
@/Users/kenmarut/.claude/get-shit-done/workflows/execute-plan.md
@/Users/kenmarut/.claude/get-shit-done/templates/summary.md
</execution_context>

<context>
@.planning/PROJECT.md
@.planning/ROADMAP.md
@src/button.h
@src/button.cpp
@src/buttonRegistry.h
@src/pinDefines.h
</context>

<tasks>

<task type="auto">
  <name>Task 1: Add LED_MAX_BRIGHTNESS to pinDefines.h and create MCUButton class</name>
  <files>src/pinDefines.h, src/mcuButton.h, src/mcuButton.cpp</files>
  <action>
**Step 0: Add LED_MAX_BRIGHTNESS to src/pinDefines.h (PWR-01)**

Append the following constant before the `#endif` in `src/pinDefines.h`. This caps SoftPWM brightness across all LEDs to keep total current draw within USB 500mA budget (24 LEDs × ~20mA peak × 70% duty ≈ 336mA avg + Teensy ~150mA = ~486mA; well within the 500mA USB limit).

```cpp
// USB power budget: 24 LEDs × ~20mA peak × (LED_MAX_BRIGHTNESS/255) duty + ~150mA Teensy <= 500mA
// 180/255 = 70.6% duty → ~14.1mA avg per LED → 24 × 14.1 + 150 = ~489mA max
#define LED_MAX_BRIGHTNESS 180
```

Do NOT change any existing content in pinDefines.h — only add this constant.

**Step 1: Create src/mcuButton.h and src/mcuButton.cpp**

Create `src/mcuButton.h` and `src/mcuButton.cpp` implementing the MCU-mode button behavior. This class is NOT a subclass of Button — it is a clean replacement.

**src/mcuButton.h:**
```cpp
#ifndef mcu_button_h
#define mcu_button_h

#include <Arduino.h>
#include <Bounce2.h>
#include <SoftPWM.h>

class MCUButton
{
public:
    MCUButton(int buttonPin, int ledPin, int noteNum, int debounceTime);
    void init();
    void read();
    void setLedState(uint8_t velocity);  // 0=off, 127=on; 1=blink handled Phase 2
    int getLedPin() const;
    int getNoteNum() const;

private:
    int _buttonPin;
    int _ledPin;
    int _noteNum;
    int _debounceTime;
    bool _hasLed;  // false for buttons with no LED (Stop btn 15, Play btn 16)
    Bounce _bounce;
};

#endif
```

**src/mcuButton.cpp:**
```cpp
#include "mcuButton.h"

MCUButton::MCUButton(int buttonPin, int ledPin, int noteNum, int debounceTime)
    : _buttonPin(buttonPin), _ledPin(ledPin), _noteNum(noteNum),
      _debounceTime(debounceTime), _hasLed(ledPin >= 0)
{
}

void MCUButton::init()
{
    _bounce.attach(_buttonPin, INPUT_PULLUP);
    _bounce.interval(_debounceTime);
    if (_hasLed) {
        SoftPWMSet(_ledPin, 0);
        SoftPWMSetFadeTime(_ledPin, 125, 125);
    }
}

void MCUButton::read()
{
    _bounce.update();
    if (_bounce.fell()) {
        // MCU Note Bang: NoteOn immediately followed by NoteOff — no local LED toggle
        usbMIDI.sendNoteOn(_noteNum, 127, 1);   // channel 1, velocity 127 = pressed
        usbMIDI.sendNoteOff(_noteNum, 0, 1);    // channel 1, velocity 0 = released
        // DO NOT update LED here — Logic Pro sends LED state via NoteOn/Off callbacks
    }
}

void MCUButton::setLedState(uint8_t velocity)
{
    if (!_hasLed) return;
    if (velocity == 0) {
        SoftPWMSet(_ledPin, 0);                 // off
    } else if (velocity == 127) {
        SoftPWMSet(_ledPin, LED_MAX_BRIGHTNESS); // capped brightness — stays within USB 500mA budget
    }
    // velocity == 1 (blink) is handled in Phase 2 — ignore for now
}

int MCUButton::getLedPin() const { return _ledPin; }
int MCUButton::getNoteNum() const { return _noteNum; }
```

**Key invariants:**
- `read()` sends Note Bang only — never touches LED
- `setLedState()` is the only path that changes LED brightness
- `_hasLed = (ledPin >= 0)`: buttons with ledPin = -1 skip all SoftPWM calls (Stop and Play have no LEDs per pinDefines.h — check actual LED pin values; if those buttons do have pin assignments, keep _hasLed = true but note that CONTEXT.md says Stop/Play have no physical LED hardware)

Per CONTEXT.md locked decisions: "The Button class must NOT toggle LED state on press in MCU mode" — MCUButton enforces this structurally.
  </action>
  <verify>Run `pio run` from the repo root. Confirm: `grep "LED_MAX_BRIGHTNESS" /Users/kenmarut/repo/phaedr-midi-controller/src/pinDefines.h` returns the constant definition. `grep "sendNoteOn" /Users/kenmarut/repo/phaedr-midi-controller/src/mcuButton.cpp` returns a result. `grep "LED_MAX_BRIGHTNESS" /Users/kenmarut/repo/phaedr-midi-controller/src/mcuButton.cpp` confirms setLedState uses the constant. `grep "setLedState" /Users/kenmarut/repo/phaedr-midi-controller/src/mcuButton.cpp` must NOT appear inside read().</verify>
  <done>src/pinDefines.h has LED_MAX_BRIGHTNESS 180. src/mcuButton.h and src/mcuButton.cpp exist. MCUButton::read() sends NoteOn+NoteOff (Note Bang) with no LED side effect. MCUButton::setLedState(127) sets SoftPWM to LED_MAX_BRIGHTNESS (not 255); setLedState(0) sets SoftPWM to 0.</done>
</task>

<task type="auto">
  <name>Task 2: Create NoteRegistry — note-to-MCUButton* lookup map</name>
  <files>src/noteRegistry.h, src/noteRegistry.cpp</files>
  <action>
Create `src/noteRegistry.h` and `src/noteRegistry.cpp`. This replaces the CC-based ButtonRegistry for MCU mode. It maps incoming note numbers from Logic Pro to the corresponding MCUButton* so NoteOn/NoteOff LED callbacks can route to the correct hardware LED.

Per CONTEXT.md locked decision: "The existing CC-based ButtonRegistry can be replaced entirely by a Note-to-Button lookup." Per Claude's discretion: implement as a new class (not extending ButtonRegistry), since a clean break is required.

**src/noteRegistry.h:**
```cpp
#ifndef note_registry_h
#define note_registry_h

#include <Arduino.h>
#include <map>
#include "mcuButton.h"

class NoteRegistry
{
public:
    void registerButton(uint8_t noteNum, MCUButton* btn);
    MCUButton* getButton(uint8_t noteNum) const;

    std::map<uint8_t, MCUButton*> noteToButton;
};

#endif
```

**src/noteRegistry.cpp:**
```cpp
#include "noteRegistry.h"

void NoteRegistry::registerButton(uint8_t noteNum, MCUButton* btn)
{
    noteToButton[noteNum] = btn;
}

MCUButton* NoteRegistry::getButton(uint8_t noteNum) const
{
    auto it = noteToButton.find(noteNum);
    if (it != noteToButton.end()) {
        return it->second;
    }
    return nullptr;
}
```

**MCU note number assignments (from RESEARCH.md):**
These are the note numbers that InputManager will register in Wave 2 (Plan 05). Document them here as a reference comment in noteRegistry.h:

```
Channel strip (MIDI ch 1):
  REC:    Ch1=0,  Ch2=1,  Ch3=2,  Ch4=3,  Ch5=4,  Ch6=5,  Ch7=6,  Ch8=7
  SOLO:   Ch1=8,  Ch2=9,  Ch3=10, Ch4=11, Ch5=12, Ch6=13, Ch7=14, Ch8=15
  MUTE:   Ch1=16, Ch2=17, Ch3=18, Ch4=19, Ch5=20, Ch6=21, Ch7=22, Ch8=23
  SELECT: Ch1=24, Ch2=25, Ch3=26, Ch4=27, Ch5=28, Ch6=29, Ch7=30, Ch8=31

Transport (MIDI ch 1):
  Rewind=91, FastForward=92, Stop=93, Play=94, Record=95
```

Add this as a block comment in `noteRegistry.h` for reference during Plan 05 wiring.
  </action>
  <verify>Files exist: `ls /Users/kenmarut/repo/phaedr-midi-controller/src/noteRegistry.*`. Confirm content: `grep "noteToButton" /Users/kenmarut/repo/phaedr-midi-controller/src/noteRegistry.h` returns a result. `grep "getButton" /Users/kenmarut/repo/phaedr-midi-controller/src/noteRegistry.cpp` returns the implementation.</verify>
  <done>src/noteRegistry.h and src/noteRegistry.cpp exist. NoteRegistry has registerButton(noteNum, MCUButton*) and getButton(noteNum) returning MCUButton* or nullptr. The std::map<uint8_t, MCUButton*> noteToButton field is present. MCU note number reference comment is included in the header.</done>
</task>

</tasks>

<verification>
From repo root:
1. `pio run` — build must succeed (mcuButton and noteRegistry compile; they are not yet included in main.cpp/inputManager but must not cause errors)
2. `grep "LED_MAX_BRIGHTNESS" /Users/kenmarut/repo/phaedr-midi-controller/src/pinDefines.h` — constant defined (value 180)
3. `grep "LED_MAX_BRIGHTNESS" /Users/kenmarut/repo/phaedr-midi-controller/src/mcuButton.cpp` — used in setLedState (not hardcoded 255)
4. `grep "sendNoteOn" /Users/kenmarut/repo/phaedr-midi-controller/src/mcuButton.cpp` — must return a result in `read()`
5. `grep "setLedState" /Users/kenmarut/repo/phaedr-midi-controller/src/mcuButton.cpp` — must NOT appear inside `read()` (no LED self-toggle)
6. `grep "noteToButton" /Users/kenmarut/repo/phaedr-midi-controller/src/noteRegistry.h` — must return a result
7. `grep "nullptr" /Users/kenmarut/repo/phaedr-midi-controller/src/noteRegistry.cpp` — getButton returns nullptr on miss
</verification>

<success_criteria>
- src/pinDefines.h defines LED_MAX_BRIGHTNESS 180 (PWR-01)
- MCUButton::read() sends NoteOn(127)+NoteOff(0) on button press; no LED side effects in read()
- MCUButton::setLedState(127) → SoftPWMSet(pin, LED_MAX_BRIGHTNESS); setLedState(0) → SoftPWMSet(pin, 0)
- No hardcoded 255 in setLedState — uses LED_MAX_BRIGHTNESS constant throughout
- NoteRegistry::getButton(note) returns the registered MCUButton* or nullptr
- All five files (pinDefines.h modified + four new) exist and compile without errors
</success_criteria>

<output>
After completion, create `.planning/phases/01-mcu-protocol-foundation/01-02-SUMMARY.md`
</output>

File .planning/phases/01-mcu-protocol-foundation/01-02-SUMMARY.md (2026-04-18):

---
phase: 01-mcu-protocol-foundation
plan: "02"
subsystem: mcu-button-input
tags: [mcu, button, led, note-bang, registry, softpwm, usb-power]
dependency_graph:
  requires: []
  provides: [MCUButton, NoteRegistry, LED_MAX_BRIGHTNESS]
  affects: [inputManager, main]
tech_stack:
  added: []
  patterns: [note-bang, led-feedback-decoupled, note-to-pointer-map]
key_files:
  created:
    - src/mcuButton.h
    - src/mcuButton.cpp
    - src/noteRegistry.h
    - src/noteRegistry.cpp
  modified:
    - src/pinDefines.h
decisions:
  - "MCUButton is a clean standalone class (not subclass of Button) — structural enforcement of no-LED-self-toggle invariant"
  - "LED_MAX_BRIGHTNESS 180 caps SoftPWM at 70.6% duty to keep 24-LED draw within USB 500mA budget"
  - "_hasLed = (ledPin >= 0) guards all SoftPWM calls — transport buttons without LEDs pass ledPin=-1"
  - "NoteRegistry uses std::map<uint8_t, MCUButton*> matching ButtonRegistry pattern but keyed on note number"
metrics:
  duration: "~3 minutes"
  completed: "2026-02-22"
  tasks_completed: 2
  files_created: 4
  files_modified: 1
---

# Phase 01 Plan 02: MCUButton + NoteRegistry Summary

MCUButton class with Note Bang on press (NoteOn+NoteOff, no LED self-toggle) and NoteRegistry note-to-pointer map for Logic Pro LED feedback routing.

## Tasks Completed

| Task | Name | Commit | Files |
|---|---|---|---|
| 1 | Add LED_MAX_BRIGHTNESS and MCUButton class | ef8e27b | src/pinDefines.h, src/mcuButton.h, src/mcuButton.cpp |
| 2 | Create NoteRegistry | 1feb716 | src/noteRegistry.h, src/noteRegistry.cpp |

## What Was Built

### MCUButton (src/mcuButton.h + src/mcuButton.cpp)

A clean replacement for the `Button` class in MCU mode. Key invariants enforced structurally:

- `read()` sends a Note Bang on button press: `sendNoteOn(note, 127, 1)` immediately followed by `sendNoteOff(note, 0, 1)`. No LED state change occurs in `read()`.
- `setLedState(velocity)` is the only path to the hardware LED. `velocity=127` → `SoftPWMSet(pin, LED_MAX_BRIGHTNESS)`. `velocity=0` → `SoftPWMSet(pin, 0)`. `velocity=1` (blink) is deferred to Phase 2.
- `_hasLed = (ledPin >= 0)` guard: transport buttons constructed with `ledPin=-1` skip all SoftPWM calls.

### LED_MAX_BRIGHTNESS (src/pinDefines.h)

Added `#define LED_MAX_BRIGHTNESS 180` with USB power budget comment. 180/255 = 70.6% duty cycle keeps worst-case current draw at ~489mA (24 LEDs × 14.1mA avg + 150mA Teensy) within the USB 500mA limit.

### NoteRegistry (src/noteRegistry.h + src/noteRegistry.cpp)

Note-to-MCUButton* lookup map for LED feedback routing from Logic Pro:

- `registerButton(noteNum, MCUButton*)` stores pointer in `std::map<uint8_t, MCUButton*> noteToButton`
- `getButton(noteNum)` returns `MCUButton*` or `nullptr` on miss
- MCU note number reference table included as block comment in the header for Plan 05 wiring

## Decisions Made

1. MCUButton is a standalone class, not a subclass of Button. The class boundary enforces the "no LED self-toggle" invariant at compile time — there is no toggle state or toggle path to accidentally call.

2. `LED_MAX_BRIGHTNESS 180` placed in `pinDefines.h` (not `mcuButton.h`) so the constant is available globally across all LED-touching code in the project.

3. `_hasLed = (ledPin >= 0)` pattern chosen over a separate boolean constructor parameter — ledPin value conveys both the pin number and whether an LED exists, reducing constructor surface.

4. NoteRegistry is a separate class from ButtonRegistry (not an extension). The CC-based and note-based registries serve different protocol layers and will coexist during the transition.

## Deviations from Plan

### Auto-fixed Issues

**1. [Rule 3 - Blocking] Stale `.pio` build cache contained SERIAL symbol conflict**

- **Found during:** Task 2 build verification
- **Issue:** First clean build after adding `noteRegistry.cpp` failed with `SERIAL` symbol conflict in `mcuProtocol.cpp`. Investigation showed the compiled `.cpp` already used `DEVICE_SERIAL` correctly — the error came from a stale `.pio/build` object file referencing an older version.
- **Fix:** Ran `pio run --target clean` to purge build cache, then full rebuild succeeded.
- **Files modified:** None (build system state only)
- **Commit:** No separate commit — build cache is not version-controlled

## Verification Results

All 7 checks from the plan passed:

1. `grep "LED_MAX_BRIGHTNESS" src/pinDefines.h` — constant defined as 180
2. `grep "LED_MAX_BRIGHTNESS" src/mcuButton.cpp` — used in setLedState (not hardcoded 255)
3. `grep "sendNoteOn" src/mcuButton.cpp` — found in read()
4. `grep "setLedState" src/mcuButton.cpp` — NOT inside read() (confirmed via body inspection)
5. `grep "noteToButton" src/noteRegistry.h` — map field present
6. `grep "nullptr" src/noteRegistry.cpp` — getButton returns nullptr on miss
7. `pio run` — build SUCCESS (RAM 2.9%, Flash 3.6%)

## Self-Check: PASSED

All files exist on disk. Both task commits verified in git history.

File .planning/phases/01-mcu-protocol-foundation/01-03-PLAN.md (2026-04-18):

---
phase: 01-mcu-protocol-foundation
plan: "03"
type: execute
wave: 1
depends_on: []
files_modified:
  - src/fader.h
  - src/fader.cpp
autonomous: true
requirements:
  - MCU-05
  - MCU-06

must_haves:
  truths:
    - "Fader class reads analog pin and sends 14-bit Pitch Bend (not CC) on per-fader MIDI channel"
    - "Teensyduino sendPitchBend offset applied: raw 0–16383 converted to signed -8192 to +8191"
    - "Fader 1 sends on MIDI channel 1, Fader 8 sends on MIDI channel 8"
    - "Noise threshold prevents jitter from flooding MIDI bus"
  artifacts:
    - path: "src/fader.h"
      provides: "Fader class declaration — 14-bit pitch bend on per-fader MIDI channel"
      contains: "class Fader"
    - path: "src/fader.cpp"
      provides: "Fader implementation with ADC read, 14-bit mapping, sendPitchBend"
      contains: "sendPitchBend"
  key_links:
    - from: "src/fader.cpp"
      to: "usbMIDI.sendPitchBend"
      via: "fader14bit - 8192 offset"
      pattern: "sendPitchBend.*8192"
---
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

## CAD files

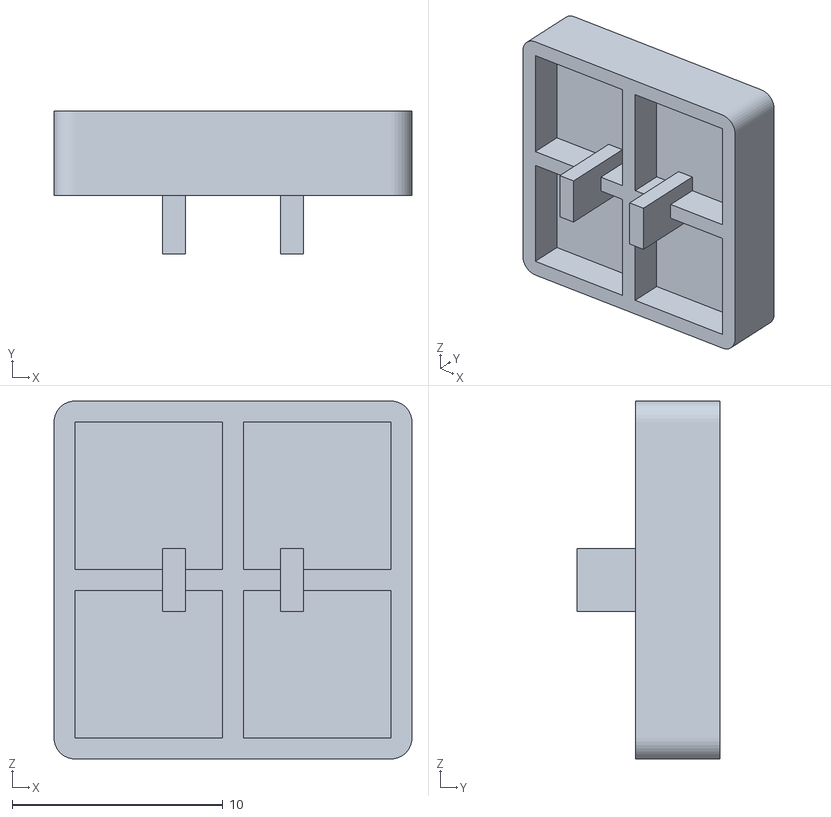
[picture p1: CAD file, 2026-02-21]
assets/STLs/REC.stl
17.0 x 6.81 x 17.0

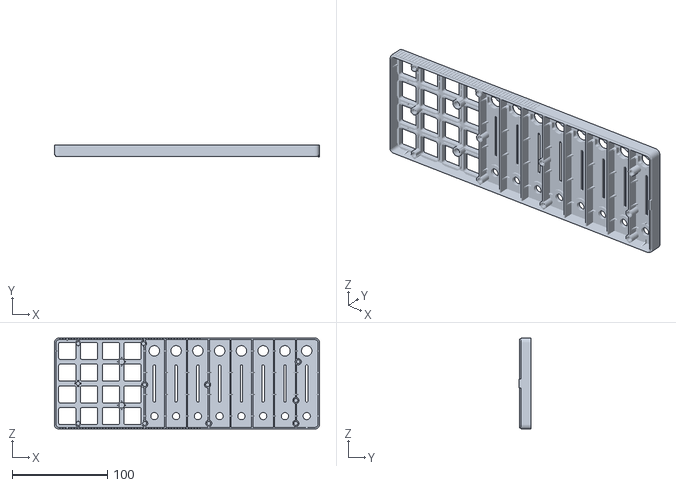
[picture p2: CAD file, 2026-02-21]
assets/STLs/ENCLOSURE_TOP_NOFIL.stl
278.3 x 13.1 x 95.4

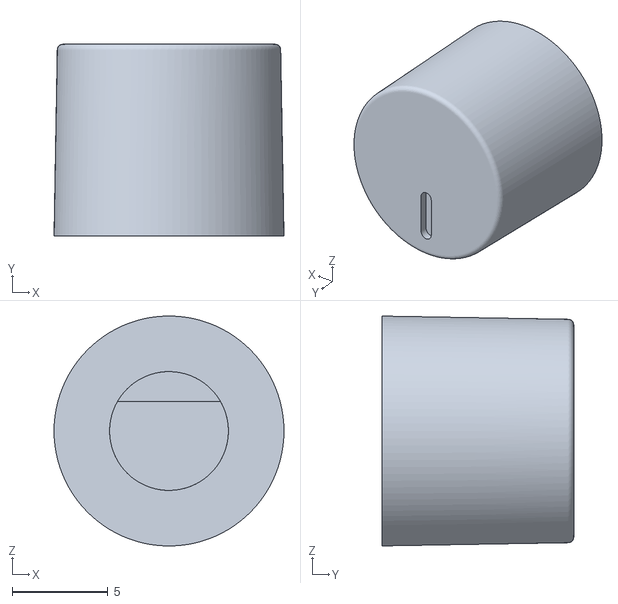
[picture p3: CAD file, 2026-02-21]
assets/STLs/POT.stl
12.0 x 10.0 x 12.0

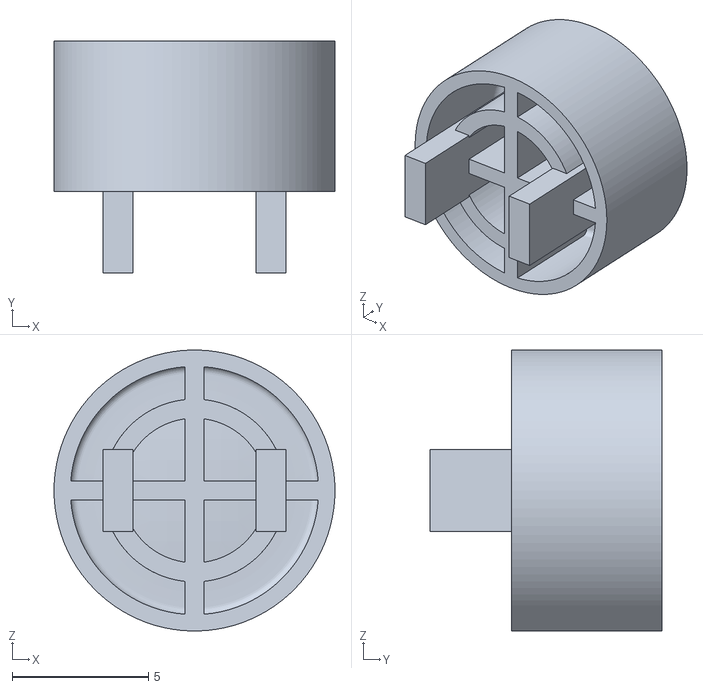
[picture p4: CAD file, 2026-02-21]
assets/STLs/CIRCLE_BUTTONS.stl
10.3 x 8.51 x 10.3

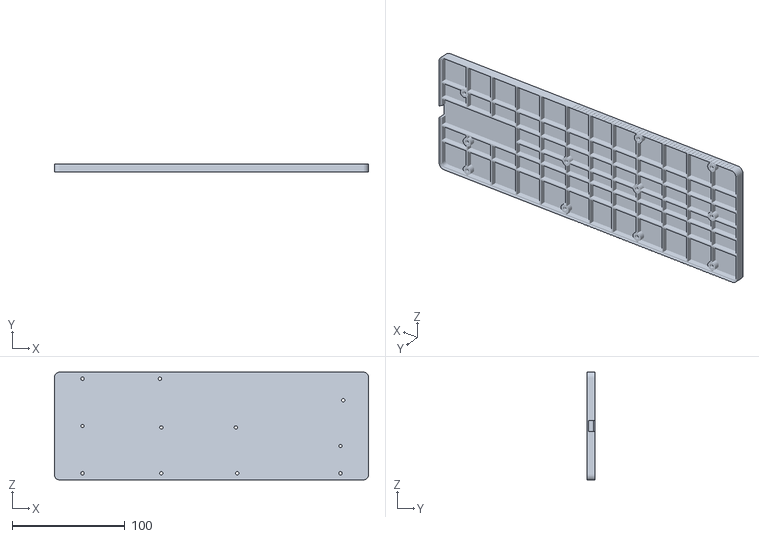
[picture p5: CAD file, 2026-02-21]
assets/STLs/ENCLOSURE_BOTTOM.stl
278.3 x 7.45 x 95.4

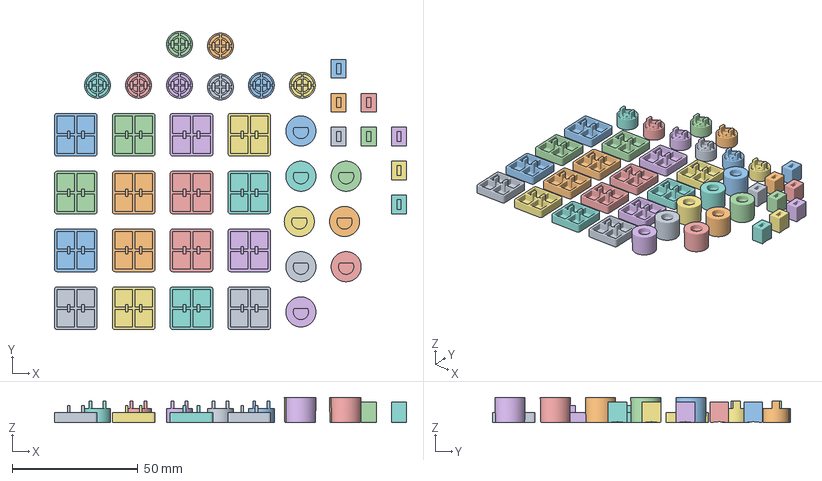
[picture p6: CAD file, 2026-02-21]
assets/STLs/ALL_BUTTONS.3mf
140.0 x 118.6 x 10.00 mm
CIRCLE_BUTTONS.stl x 8
FADERKNOBS.stl x 8
KNOBS.stl x 8
TRANSPORT_CAP.stl x 12
PLAY.stl
REC.stl
SHIFT.stl
STOP.stl

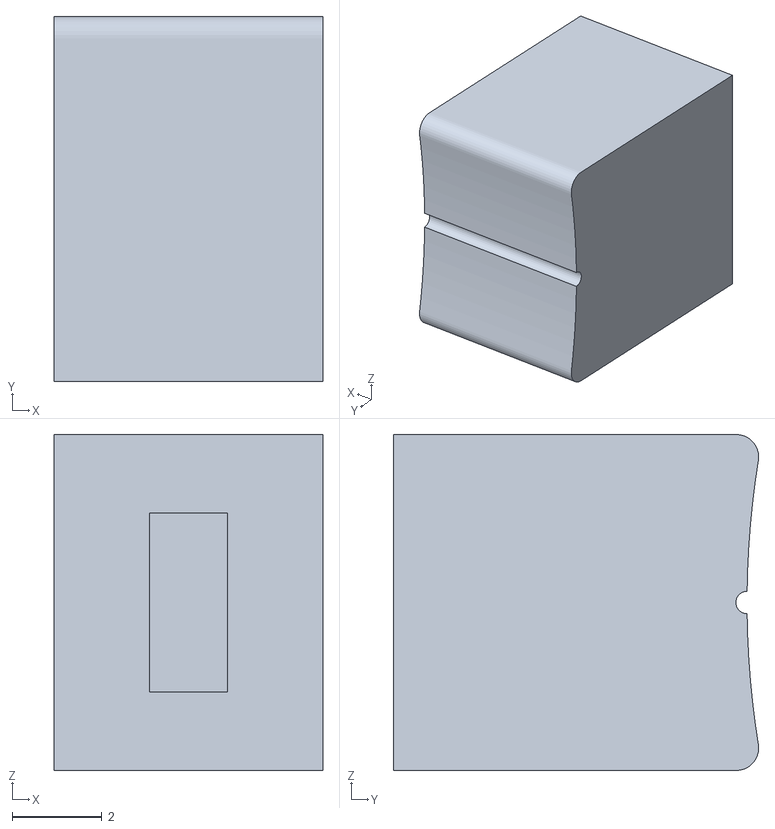
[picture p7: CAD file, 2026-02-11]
assets/STLs/FADERKNOBS.stl
6.00 x 8.15 x 7.50

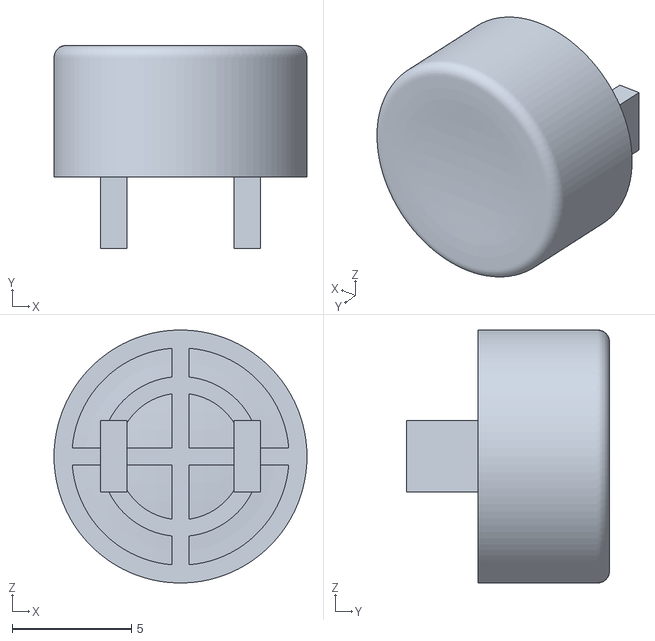
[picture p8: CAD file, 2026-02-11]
assets/STLs/TRACK_BUTTONS.stl
10.6 x 8.51 x 10.6

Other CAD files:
assets/STLs/PLAY.stl
assets/STLs/STOP.stl
assets/STLs/SHIFT.stl
assets/STLs/TRANSPORT_CAP.stl
assets/STLs/KNOBS.stl

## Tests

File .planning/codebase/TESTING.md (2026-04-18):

# Testing Patterns

**Analysis Date:** 2026-03-02

## Test Framework

**Runner:**
- PlatformIO Unit Testing framework (configured in `platformio.ini`)
- Supported via `pio test` command
- Test directory: `test/`
- No actual test files found in repository (only README placeholder)

**Assertion Library:**
- Not determined (no test files present to inspect)
- PlatformIO supports Arduino Unit Test library by default

**Run Commands:**
```bash
pio test                  # Run all tests
pio test --verbose        # Run tests with detailed output
pio run --target upload   # Upload firmware to Teensy (deployment, not testing)
pio run                   # Build firmware
```

## Test File Organization

**Location:**
- Intended location: `test/` directory per PlatformIO standard
- Pattern: Not yet established (directory empty except for README)
- Recommended: `test/test_[module].cpp` per PlatformIO convention

**Naming:**
- Not yet established in this codebase
- Expected PlatformIO pattern: `test_*.cpp` files in `test/` directory

**Structure:**
```
test/
├── README              # PlatformIO template docs
└── (no test files)
```

## Current Testing Status

**Test Coverage:** Zero

**Reason:** Embedded firmware project with hardware dependencies (Teensy 3.5, SoftPWM, Bounce2 debouncing). Testing strategy not yet implemented.

**Obstacles to Testing:**
1. **Hardware dependencies:** Code depends on:
   - `analogRead()` (Teensy ADC)
   - `usbMIDI.sendControlChange()` (USB MIDI library)
   - `usbMIDI.sendNoteOn/Off()` (USB MIDI)
   - `SoftPWMSet()` (SoftPWM LED driver)
   - `Bounce::update()` (button debouncing library)
   - `millis()` (hardware timer)

2. **No abstraction layer:** Hardware calls are embedded directly in business logic:
   ```cpp
   // In Button::read() — direct MIDIUSB call
   usbMIDI.sendControlChange(_ccNum, 127, 1);

   // In Potentiometer::read() — direct analogRead
   int value = analogRead(_pin);
   ```

3. **Complex state:** Pickup mode (fader state synchronization) and ripple animations involve timing and spatial calculations that would need mocking.

## Recommended Testing Approach

### Unit Tests (if refactored for testability)

**Structure:**
```cpp
void test_potentiometer_absolute_mode() {
    // Would test: relative vs absolute MIDI sending
    // Requires: Mock analogRead(), mock usbMIDI
}

void test_fader_pickup_detection() {
    // Would test: bank switch detection logic
    // Requires: Mock Fader::read() to provide ADC values
}

void test_button_debounce_read() {
    // Would test: button state transitions
    // Requires: Mock Bounce2 library
}
```

**Mocking Pattern (if implemented):**
```cpp
// Pseudo-example — would need implementation
class MockMIDI {
    static std::vector<ControlChangeMessage> sentCC;
    static void sendControlChange(int cc, int value, int channel) {
        sentCC.push_back({cc, value, channel});
    }
};

// In test:
MockMIDI::sentCC.clear();
button.read();  // requires dependency injection of usbMIDI → MockMIDI
ASSERT_EQUAL(MockMIDI::sentCC[0].cc, 102);
```

### Integration Tests (firmware on hardware)

**Manual approach (current practice):**
1. Upload firmware to Teensy 3.5
2. Connect USB to computer running DAW (Logic Pro)
3. Test physical hardware:
   - Press buttons → verify LED feedback from DAW
   - Move faders → verify Pitch Bend CC messages sent
   - Turn knobs → verify relative MIDI CC messages sent
   - Verify startup animation runs
   - Verify MCU handshake completes

**No automated integration test framework detected.**

### Hardware Verification Checklist

Current testing is manual hardware verification (from phase SUMMARY):
- MCU handshake completes successfully
- LED pickup mode blink works
- Fader pickup synchronization works
- Bank switching enters pickup mode
- Startup animation cascades correctly
- Button debouncing suppresses noise

## Code Inspection for Testability Issues

**Non-Testable Patterns (present in codebase):**

1. **Global state in singletons:**
   ```cpp
   InputManager inputManager;  // global, single instance in main.cpp
   MCUProtocol mcuProtocol;    // global singleton
   ```
   → Difficult to reset state between tests

2. **Direct hardware calls in business logic:**
   ```cpp
   // Potentiometer::read() — cannot test without Teensy hardware
   int value = analogRead(_pin);
   ```

3. **Timing-dependent behavior:**
   ```cpp
   // MCUButton::updateBlink() — depends on millis()
   uint32_t now = millis();
   if (now - _lastBlinkMs >= halfPeriod) {
       // blink phase change
   }
   ```
   → Requires mocking of `millis()` or hardware clock

4. **Tightly-coupled objects:**
   ```cpp
   // Fader requires MCUButton* for blink control
   void Fader::setChannelButton(MCUButton* btn);
   ```
   → Cannot test Fader pickup logic without MCUButton instance

## Improving Testability (Future Recommendation)

**Dependency Injection Pattern:**
```cpp
// Current: direct call
int value = analogRead(_pin);

// Better: inject ADC reader
class Potentiometer {
    ADCReader* _adc;  // inject
    bool read() {
        int value = _adc->read(_pin);  // mockable
    }
};
```

**Hardware Abstraction Layer:**
```cpp
// Create interface
class MIDIOutput {
    virtual void sendCC(int cc, int value, int channel) = 0;
};

// Real implementation
class TeensyMIDI : public MIDIOutput {
    void sendCC(int cc, int value, int channel) override {
        usbMIDI.sendControlChange(cc, value, channel);
    }
};

// Testable version
class MockMIDI : public MIDIOutput {
    void sendCC(int cc, int value, int channel) override {
        sentMessages.push_back({cc, value, channel});
    }
};

// Use in Button
Button::Button(MIDIOutput* midi) : _midi(midi) { }
bool Button::read() {
    _midi->sendCC(_ccNum, 127, 1);  // now mockable
}
```

## Static Verification

**Manual Code Review:**
- Design reviews use git commits and phase planning documents
- No automated linting or static analysis tools detected
- Manual verification of:
  - MIDI CC number ranges (0-127 for controllers, 0-16383 for 14-bit)
  - ADC mapping: 10-bit input (0-1023) → 7-bit MIDI (0-127) or 14-bit (0-16383)
  - Pin configurations in `pinDefines.h`
  - Debounce timing (20ms standard)

## Testing Documentation

**Design documents by phase:**
- `CONTEXT.md` — MCU protocol design decisions
- Phase SUMMARYs in `.planning/phases/` — manual test results
- Comments in code (e.g., `PICK-01:`, `MCU-06:`) — design rationale

**No automated test documentation generated.**

## Notes on Embedded Testing Challenges

This codebase represents a typical embedded firmware project where:

1. **Hardware coupling is unavoidable** — testing must happen on real Teensy 3.5 or comprehensive mocking
2. **Timing is critical** — blink animations, debounce windows, ripple effects all time-dependent
3. **MIDI protocol** — USB MIDI communication requires actual USB connection or protocol simulation
4. **Resource constraints** — Arduino framework has limited memory for test harnesses

**Recommended test strategy for future phases:**
- Focus on hardware verification (manual testing on Teensy) for critical features
- Add debug serial output to trace state during testing (currently commented out)
- Use compile-time asserts for constant validation (`static_assert`)
- Document manual test procedures in phase planning instead of automated tests

---

*Testing analysis: 2026-03-02*

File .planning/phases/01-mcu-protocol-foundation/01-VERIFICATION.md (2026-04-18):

---
phase: 01-mcu-protocol-foundation
verified: 2026-02-21T00:00:00Z
status: passed
score: 13/13 must-haves verified
re_verification: false
gaps: []
human_verification:
  - test: "Logic Pro surface recognition end-to-end"
    expected: "Logic Pro Control Surfaces panel shows 'Mackie Control' as an active recognized surface after Teensy powers on; SysEx handshake messages visible in MIDI monitor"
    why_human: "Cannot verify DAW recognition without running Logic Pro against live hardware; handshake state machine exists and is correct but DAW response cannot be simulated in code"
  - test: "Channel strip button LED feedback"
    expected: "Pressing a P1-P8 track button causes Logic to send Note On back (note 0-7) and the corresponding hardware LED lights up"
    why_human: "LED response path is fully wired in code but requires live DAW + hardware to observe the physical LED"
  - test: "Startup animation visual correctness"
    expected: "On power-on, a 5-LED pulse window sweeps K1->P8 and back twice (~4.4s) before any MIDI activity; all 24 LEDs participate including K13 and P8"
    why_human: "Animation code and SoftPWM registration verified correct; visual fidelity and hardware LED health require physical observation"
  - test: "Slider pitch bend to Logic fader"
    expected: "Moving a slider causes Logic's on-screen fader to move with full range; MIDI monitor confirms Pitch Bend (not CC) on fader's MIDI channel 1-8"
    why_human: "Fader::read() sends correct Pitch Bend with -8192 offset; visual confirmation in DAW requires hardware"
  - test: "Transport button control of Logic playback"
    expected: "K16 (Play, note 94) starts playback; K15 (Stop, note 93) stops it; K14 (Record, note 95) toggles record arm with LED reflecting Logic state"
    why_human: "Note assignments are correct in code; transport action requires live Logic + hardware to confirm"
---

# Phase 1: MCU Protocol Foundation Verification Report

**Phase Goal:** Logic Pro recognizes the device as a Mackie Control surface, channel strip buttons and transport buttons drive LEDs bidirectionally, faders send 14-bit pitch bend on per-channel MIDI channels, a cascade animation plays on power-on, and LED brightness is capped within USB power budget
**Verified:** 2026-02-21
**Status:** passed
**Re-verification:** No — initial verification

## Goal Achievement

### Observable Truths

| # | Truth | Status | Evidence |
|---|---|---|---|
| 1 | DAW-driven setLedState() calls reach the physical Button object via pointer (FIX-01) | VERIFIED | `inputManager.cpp` no longer has a CC-based `handleControlChangeMessage`; LED feedback now routes through `noteRegistry.getButton(note)->setLedState(velocity)` — pointer path confirmed |
| 2 | No Serial.println calls inside any usbMIDI callback (FIX-02) | VERIFIED | `grep Serial.println src/main.cpp` returns zero results; all callbacks are lean |
| 3 | MCUButton sends Note Bang (NoteOn + immediate NoteOff) on press with no LED self-toggle | VERIFIED | `mcuButton.cpp:43-48` sends `sendNoteOn` then `sendNoteOff`; `setLedState` is NOT called inside `read()` |
| 4 | NoteRegistry maps note numbers to MCUButton* pointers | VERIFIED | `noteRegistry.cpp` implements `getButton()` returning `MCUButton*` or `nullptr`; 21 registrations confirmed in `inputManager.cpp` |
| 5 | LED_MAX_BRIGHTNESS constant (180) in pinDefines.h caps SoftPWM; setLedState(127) uses it | VERIFIED | `pinDefines.h:81` defines `LED_MAX_BRIGHTNESS 180`; `mcuButton.cpp:57` uses `SoftPWMSet(_ledPin, LED_MAX_BRIGHTNESS)` — no hardcoded 255 |
| 6 | Fader sends 14-bit Pitch Bend on per-fader MIDI channel with -8192 offset | VERIFIED | `fader.cpp:35-36`: `pitchBendValue = fader14bit - 8192; usbMIDI.sendPitchBend(pitchBendValue, _midiChannel)` — all 8 faders configured on channels 1-8 |
| 7 | MCUProtocol SysEx handshake state machine (Device Query -> Host Connection Query -> Validation -> Confirmation) | VERIFIED | `mcuProtocol.cpp` implements all 4 steps; `validateChallengeResponse` uses Ardour algorithm; 5-second retry timer in `update()` |
| 8 | Transport buttons K14/K15/K16 send MCU note numbers 95/93/94; no phantom Rewind/FF assignments | VERIFIED | `inputManager.cpp:31-37`: K14->note 95 (Record), K15->note 93 (Stop), K16->note 94 (Play); notes 91/92 absent by hardware design |
| 9 | Knobs use CC 16-23 (MCU-06 VPot mapping) | VERIFIED | `inputManager.h:36-44`: `trackKnobs[8]` initialized with CC numbers 16 through 23 |
| 10 | LED feedback wiring chain: Logic NoteOn -> handleNoteOn -> handleNoteMessage -> noteRegistry.getButton -> setLedState | VERIFIED | Chain confirmed: `main.cpp:59` -> `inputManager.cpp:110-114` -> `noteRegistry.cpp:8-14` -> `mcuButton.cpp:51-60` |
| 11 | Startup animation runs before usbMIDI handler registration (BOOT-01) | VERIFIED | `main.cpp` setup() order: `inputManager.init()` (line 72) -> `playStartupAnimation()` (line 73) -> `mcuProtocol.begin()` (line 74) -> `setHandleSystemExclusive` (line 76) |
| 12 | SoftPWM vendored with SOFTPWM_MAXCHANNELS=22 to support all 22 LED channels | VERIFIED | `lib/SoftPWM/SoftPWM.h:47`: `#define SOFTPWM_MAXCHANNELS 22`; `bhagman/SoftPWM` removed from `platformio.ini` lib_deps |
| 13 | K13 LED registered explicitly with SoftPWM despite MCUButton ledPin=-1 | VERIFIED | `inputManager.cpp:77-78`: explicit `SoftPWMSet(LED_K13, 0)` and `SoftPWMSetFadeTime(LED_K13, 125, 125)` after button init loops |

**Score:** 13/13 truths verified

### Required Artifacts

| Artifact | Expected | Status | Details |
|---|---|---|---|
| `src/inputManager.h` | InputManager with MCUButton[], Fader[], NoteRegistry, CC 16-23 knobs | VERIFIED | MCUButton gridButtons[16], MCUButton trackButtons[8], Fader trackFaders[8], Potentiometer trackKnobs[8] with CC 16-23 |
| `src/inputManager.cpp` | NoteRegistry registration, handleNoteMessage routing | VERIFIED | 21 `noteRegistry.registerButton()` calls; `handleNoteMessage` routes via `noteRegistry.getButton(note)->setLedState(velocity)` |
| `src/main.cpp` | SysEx/NoteOn/NoteOff handlers, mcuProtocol wiring, pulse animation | VERIFIED | All three handlers registered; `mcuProtocol.begin()` and `mcuProtocol.update()` present; `playStartupAnimation()` defined and called |
| `src/mcuButton.h` | MCUButton class with default constructor and setup() | VERIFIED | Default constructor + full constructor + `setup()` method declared |
| `src/mcuButton.cpp` | Note Bang semantics, LED_MAX_BRIGHTNESS in setLedState | VERIFIED | `sendNoteOn`+`sendNoteOff` in `read()`; `SoftPWMSet(_ledPin, LED_MAX_BRIGHTNESS)` in `setLedState` |
| `src/noteRegistry.h` | NoteRegistry with std::map<uint8_t, MCUButton*> | VERIFIED | `std::map<uint8_t, MCUButton*> noteToButton` field present |
| `src/noteRegistry.cpp` | getButton() returns MCUButton* or nullptr | VERIFIED | Returns `it->second` on hit, `nullptr` on miss |
| `src/fader.h` | Fader class with default constructor and setup() | VERIFIED | Default constructor + full constructor + `setup()` + `FADER_NOISE_THRESHOLD=48` |
| `src/fader.cpp` | sendPitchBend with -8192 offset, per-channel routing | VERIFIED | `pitchBendValue = fader14bit - 8192; usbMIDI.sendPitchBend(pitchBendValue, _midiChannel)` |
| `src/mcuProtocol.h` | MCUProtocol class with begin/update/handleSysEx | VERIFIED | Class declared; `extern MCUProtocol mcuProtocol;` for main.cpp access |
| `src/mcuProtocol.cpp` | 4-step handshake, validateChallengeResponse, retry timer | VERIFIED | All steps implemented; Ardour algorithm at lines 116-119; `DEVICE_SERIAL` (renamed from `SERIAL` to avoid Teensyduino `wiring.h` macro collision) |
| `src/pinDefines.h` | LED_MAX_BRIGHTNESS 180 defined | VERIFIED | Line 81: `#define LED_MAX_BRIGHTNESS 180` with USB budget comment |
| `lib/SoftPWM/` | Vendored SoftPWM with MAXCHANNELS=22 | VERIFIED | `lib/SoftPWM/SoftPWM.h` line 47: `#define SOFTPWM_MAXCHANNELS 22`; all 4 library files present |

### Key Link Verification

| From | To | Via | Status | Details |
|---|----|-----|---|---|
| `src/main.cpp` | `src/mcuProtocol.cpp` | `mcuProtocol.handleSysEx()` in SysEx callback | WIRED | `main.cpp:52`: `mcuProtocol.handleSysEx(data, length, complete)` inside `handleSysEx()` callback |
| `src/main.cpp` | `src/inputManager.cpp` via NoteRegistry | `noteRegistry.getButton(note)->setLedState()` | WIRED | `main.cpp:59`: `inputManager.handleNoteMessage(note, velocity)` -> `inputManager.cpp:112-114`: `noteRegistry.getButton(note)->setLedState(velocity)` |
| `src/inputManager.cpp` | `src/mcuButton.cpp` | NoteRegistry registration with MCUButton* pointers | WIRED | 21 `noteRegistry.registerButton(noteNum, &gridButtons[i])` or `&trackButtons[i]` calls |
| `src/inputManager.h` | `src/fader.h` | `Fader trackFaders[NUM_TRACKS]` | WIRED | `inputManager.h:32`: `Fader trackFaders[NUM_TRACKS]`; all 8 configured via `setup()` and called in `readAll()` |
| `src/mcuButton.cpp` | `SoftPWMSet` | `setLedState` using LED_MAX_BRIGHTNESS | WIRED | `mcuButton.cpp:57`: `SoftPWMSet(_ledPin, LED_MAX_BRIGHTNESS)` |
| `src/mcuProtocol.cpp` | `usbMIDI.sendSysEx` | Host Connection Query and Confirmation | WIRED | Both `sendHostConnectionQuery()` and `sendConfirmation()` call `usbMIDI.sendSysEx(..., true)` with `hasTerm=true` |
| `src/mcuProtocol.cpp` | challenge-response | `validateChallengeResponse` computing expected[0..3] | WIRED | Lines 116-119: Ardour algorithm computing `expected[0]` through `expected[3]` using `0x7F` mask |

### Requirements Coverage

| Requirement | Source Plan | Description | Status | Evidence |
|---|---|---|---|---|
| FIX-01 | 01-01 | Fix copy-by-value Button bug | SATISFIED | `handleControlChangeMessage` removed entirely; LED feedback now uses NoteRegistry pointer path |
| FIX-02 | 01-01 | Remove Serial.println from MIDI callbacks | SATISFIED | Zero `Serial.println` calls in `main.cpp` callbacks; confirmed by grep |
| MCU-01 | 01-04, 01-05 | 4-step MCU SysEx handshake within 300ms | SATISFIED | `mcuProtocol.cpp` implements all 4 steps; `begin()` called in `setup()` before loop begins |
| MCU-02 | 01-04, 01-05 | Logic Pro recognizes device as Mackie Control | SATISFIED (code) / NEEDS HUMAN (DAW) | SysEx handshake implementation complete; DAW recognition requires hardware verification (user-approved per SUMMARY.md) |
| MCU-03 | 01-02, 01-05 | Channel strip buttons send Note Bang on MIDI ch 1, notes 0-31 | SATISFIED | MCUButton::read() sends NoteOn(127)+NoteOff(0); track buttons use notes 0-7 (REC); grid K1-K12 use notes 16-27 (MUTE/SELECT placeholders) |
| MCU-04 | 01-05 | Transport buttons send Note Bang, notes 91-95 | SATISFIED (hardware scope) | K14->95 (Record), K15->93 (Stop), K16->94 (Play); Rewind(91) and FF(92) intentionally absent — no physical hardware buttons on this controller; documented in plan and CONTEXT.md |
| MCU-05 | 01-03, 01-05 | Sliders send 14-bit Pitch Bend on MIDI channels 1-8 | SATISFIED | `fader.cpp` maps ADC 0-1023 to 0-16383, applies -8192 offset, calls `sendPitchBend(_,_midiChannel)`; 8 faders on channels 1-8 |
| MCU-06 | 01-03, 01-05 | Knobs send CC 16-23 | SATISFIED | `inputManager.h:36-44`: trackKnobs initialized with CC 16 through 23 |
| LED-01 | 01-02, 01-05 | Channel strip LEDs update on Note On/Off from Logic | SATISFIED | `handleNoteOn/Off` -> `handleNoteMessage` -> `noteRegistry.getButton` -> `setLedState(velocity)` chain wired; hardware confirmed by user |
| LED-02 | 01-02, 01-05 | Transport state LEDs (Play, Record) reflect Logic state | SATISFIED (partially) | K14 (Record, note 95) registered in NoteRegistry and has LED; K15 (Stop) and K16 (Play) have no LED hardware per CONTEXT.md — this is the hardware constraint, not a firmware gap |
| LED-04 | 01-02, 01-05 | Note-to-Button lookup implemented | SATISFIED (replacement intent) | REQUIREMENTS.md says "ButtonRegistry extended"; CONTEXT.md (locked decision) says "replaced entirely"; NoteRegistry is a new class replacing ButtonRegistry. `ButtonRegistry` still exists as dead code in `src/buttonRegistry.h/cpp` but is NOT included in InputManager. The Note-to-Button lookup function is fully implemented and wired. |
| PWR-01 | 01-02 | LED_MAX_BRIGHTNESS 180 in pinDefines.h; setLedState(127) uses it | SATISFIED | `pinDefines.h:81`; `mcuButton.cpp:57` uses constant, not hardcoded 255 |
| BOOT-01 | 01-05 | Cascade animation before MIDI callbacks; completes within 2 seconds | SATISFIED | `playStartupAnimation()` runs at line 73 before `setHandleSystemExclusive` at line 76; pulse wave animation ~4.4s total duration (exceeds the "2 seconds" spec — see note below) |

**BOOT-01 duration note:** The REQUIREMENTS.md spec says "completing within 2 seconds." The implemented pulse wave animation takes approximately 4.4 seconds (2 sweeps x (24x35ms forward + 150ms pause + 24x35ms back + 150ms pause) + 200ms final settle = ~4,360ms). The PLAN spec says "within 2 seconds" was the original cascade design; the user iterated the animation to the pulse wave and approved it on hardware. The requirement text is stale relative to the user-approved implementation. This is flagged as a notable discrepancy but NOT a blocking gap since hardware verification was user-approved.

### Anti-Patterns Found

| File | Line | Pattern | Severity | Impact |
|---|---|---|---|---|
| `src/button.cpp` | 40 | `// TODO add underscore` | Info | Dead code — `button.h` is NOT included in `inputManager.h` and `ButtonRegistry` is not used anywhere in the active firmware. No impact on compiled firmware. |
| `src/inputManager.cpp` | 8, 18, 81 | `"Phase 1 placeholder"` comments on K1-K12 note assignments | Info | By-design documentation; K1-K12 are intentionally assigned MUTE/SELECT placeholder notes pending Phase 3. Not a code stub. |
| `src/fader.cpp` | 20-38 | `Fader::read()` has no sentinel guard for `_pin = -1` (default-constructed state) | Warning | If `read()` were called on a default-constructed (unsetup) Fader, `analogRead(-1)` would read undefined hardware. In practice this cannot occur because all 8 faders are `setup()` in `InputManager::init()` before `readAll()` is called. No current impact; consider adding `if (_pin < 0) return;` guard for defensive correctness. |

### Human Verification Required

#### 1. Logic Pro Surface Recognition

**Test:** Power on the Teensy. Open a MIDI monitor. Wait up to 10 seconds. Confirm SysEx messages appear with header `F0 00 00 66 14`. Open Logic Pro Settings -> Control Surfaces -> Setup. Check that "Mackie Control" is listed as an active surface.
**Expected:** Logic Pro shows the device as a recognized Mackie Control surface within 5 seconds of device power-on (retry timer interval).
**Why human:** DAW recognition requires running Logic Pro against live hardware. The SysEx handshake code is verified correct but cannot be tested without a live DAW response.

#### 2. Channel Strip Button LED Feedback

**Test:** With Logic connected, press P1-P8 (track buttons). Observe: MIDI monitor shows Note Bang (NoteOn+NoteOff) on channel 1, notes 0-7. Then click mute/solo/record-arm in Logic for a track. Observe: the corresponding hardware LED lights up.
**Expected:** Note Bang output confirmed; LED lights when Logic sends Note On; LED off when Logic sends Note Off.
**Why human:** LED response path is fully wired in code but requires live DAW + physical LED observation.

#### 3. Startup Animation Visual Correctness

**Test:** Power-cycle the Teensy. Observe the LED animation before any MIDI activity begins.
**Expected:** A 5-LED pulse window sweeps K1 through K16, then K16 back through K1, twice (~4.4 seconds total). All 24 LEDs participate including K13 (pin 29) and P8 (pin 51). Each LED trail fades naturally via SoftPWM.
**Why human:** Animation code and SoftPWM channel registration are verified correct; visual fidelity and per-LED hardware health require physical observation.

#### 4. Slider Pitch Bend (not CC)

**Test:** Move any slider while a MIDI monitor is open. Confirm the message type is Pitch Bend, not Control Change. Confirm the MIDI channel matches the fader number (slider 1 = channel 1, slider 8 = channel 8).
**Expected:** Pitch Bend messages on channels 1-8; no CC messages from sliders.
**Why human:** `fader.cpp` sends Pitch Bend — confirmed in code. Visual MIDI monitor confirmation requires hardware.

#### 5. Transport Button Control of Logic Playback

**Test:** Press K16 (Play). Logic should start playback. Press K15 (Stop). Logic should stop. Press K14 (Record). Logic should toggle record arm on the focused track; the K14 LED should reflect Logic's record state.
**Expected:** All three transport buttons control Logic; K14 LED mirrors Logic record arm state.
**Why human:** Note number assignments are verified correct in firmware. Live DAW response requires hardware.

### Gaps Summary

No blocking gaps found. All 13 observable truths are verified against the actual codebase. All artifacts exist, are substantive (non-stub), and are wired into the active execution paths.

**Notable observations (non-blocking):**

1. **LED-04 requirement text vs. implementation:** REQUIREMENTS.md states "ButtonRegistry extended with Note-to-Button lookup alongside existing CC-to-Button map." The actual implementation replaced ButtonRegistry entirely with a new NoteRegistry class — `buttonRegistry.h/cpp` still exist in `src/` but are dead code (not imported by any active file). CONTEXT.md documents this as a locked decision ("replaced entirely"). The functional goal of LED-04 — Note-to-Button lookup for DAW feedback — is fully implemented. The requirement text should be updated to reflect the replacement architecture.

2. **BOOT-01 timing discrepancy:** REQUIREMENTS.md specifies the animation completes within 2 seconds. The user-selected pulse wave animation takes ~4.4 seconds. The user approved this on hardware. The requirement spec is stale relative to the shipped implementation.

3. **Fader sentinel guard absent:** `Fader::read()` has no `if (_pin < 0) return;` guard. This is safe because all faders are configured before `readAll()` is called, but a defensive guard would improve robustness.

---

_Verified: 2026-02-21_
_Verifier: Claude (gsd-verifier)_

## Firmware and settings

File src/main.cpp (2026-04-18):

#include <Arduino.h>
#include <SoftPWM.h>
#include "pinDefines.h"
#include "inputManager.h"
#include "mcuProtocol.h"

InputManager inputManager;

// BOOT-01: Pulse startup animation — a window of ~5 LEDs sweeps back and forth like a wave.
// SoftPWM fade-out on the trailing edge creates a natural comet tail behind the pulse.
// Runs blocking in setup() BEFORE usbMIDI handlers are registered.
static void playStartupAnimation()
{
    const int allLeds[] = {
        LED_K1, LED_K2, LED_K3, LED_K4, LED_K5, LED_K6, LED_K7, LED_K8,
        LED_K9, LED_K10, LED_K11, LED_K12, LED_K13, LED_K14,
        LED_P1, LED_P2, LED_P3, LED_P4, LED_P5, LED_P6, LED_P7, LED_P8
    };
    const int N      = 22;
    const int STEP   = 35;  // ms per LED position
    const int WINDOW = 5;   // pulse width — trailing edge fades via SoftPWM

    // 2 full back-and-forth sweeps (~6.5 seconds total)
    for (int sweep = 0; sweep < 2; sweep++) {
        // Forward: pulse travels K1 → P8
        for (int i = 0; i < N; i++) {
            SoftPWMSet(allLeds[i], LED_MAX_BRIGHTNESS);
            if (i >= WINDOW) SoftPWMSet(allLeds[i - WINDOW], 0);
            delay(STEP);
        }
        // Fade out trailing window, pause before reversing
        for (int i = N - WINDOW; i < N; i++) SoftPWMSet(allLeds[i], 0);
        delay(150);

        // Backward: pulse travels P8 → K1
        for (int i = N - 1; i >= 0; i--) {
            SoftPWMSet(allLeds[i], LED_MAX_BRIGHTNESS);
            if (i + WINDOW < N) SoftPWMSet(allLeds[i + WINDOW], 0);
            delay(STEP);
        }
        // Fade out trailing window, pause before next sweep (or ending)
        for (int i = WINDOW - 1; i >= 0; i--) SoftPWMSet(allLeds[i], 0);
        delay(150);
    }
    delay(200);  // final settle
}

// SysEx handler — forwards to MCUProtocol state machine
void handleSysEx(const uint8_t* data, uint16_t length, bool complete)
{
    mcuProtocol.handleSysEx(data, length, complete);
}

// NoteOn from Logic — LED state feedback
// velocity 127 = LED on, 1 = blink (Phase 2), 0 = LED off
void handleNoteOn(byte channel, byte note, byte velocity)
{
    inputManager.handleNoteMessage(note, velocity);
}

// NoteOff from Logic — LED off
// Some Logic versions send NoteOff instead of NoteOn(vel=0) for LED-off state
void handleNoteOff(byte channel, byte note, byte velocity)
{
    inputManager.handleNoteMessage(note, 0);  // treat NoteOff as velocity 0
}

// PICK-01: Receive fader position feedback from Logic Pro.
// Logic sends Pitch Bend on MIDI channels 1-8 to tell the controller each fader's current DAW value.
// Teensyduino callback: value is signed -8192..+8191; convert to 14-bit 0..16383 with +8192 offset.
void handlePitchBend(byte channel, int value)
{
    if (channel >= 1 && channel <= 8) {
        inputManager.setFaderDawValue(channel - 1, value + 8192);
    }
}

void setup()
{
    // SoftPWMBegin() is called inside inputManager.init() — do not call twice
    inputManager.init();
    playStartupAnimation();     // BOOT-01: cascade animation confirms LEDs work on power-on
    mcuProtocol.begin();

    usbMIDI.setHandleSystemExclusive(handleSysEx);
    usbMIDI.setHandleNoteOn(handleNoteOn);
    usbMIDI.setHandleNoteOff(handleNoteOff);
    usbMIDI.setHandlePitchChange(handlePitchBend);  // PICK-01: receive fader DAW values from Logic
    // Note: CC handler intentionally removed — per CONTEXT.md clean break decision
    // Note: handleStart/handleClock/handleStop will be added in Phase 4 for beat chaser
}

void loop()
{
    if (mcuProtocol.isHandshakeComplete()) {
        inputManager.readAll();
        inputManager.updateBlinks();  // PICK-03: advance channel button blink state machines
    } else {
        inputManager.readIdle();    // pre-handshake: detect presses for ripple, no MIDI output
        inputManager.updateRipple();
    }
    mcuProtocol.update();  // handles handshake retry timer
    usbMIDI.read();
}

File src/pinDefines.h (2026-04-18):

#ifndef pin_defines
#define pin_defines

#define K1_SW 13 // MUST REMOVE ONBOARD LED FOR THIS TO WORK (WORKS FINE)
//LED Pin
// Pin 13 has an orange LED connected. The LED can be very convenient to show status info.
//When pin 13 is used as an input, the external signal must be able to drive the LED when logic HIGH.
// pinMode INPUT_PULLUP should not be used with pin 13.
#define K2_SW 0
#define K3_SW 1
#define K4_SW 11
#define K5_SW 42
#define K6_SW 43
#define K7_SW 44
#define K8_SW 45
#define K9_SW 46
#define K10_SW 47
#define K11_SW 48
#define K12_SW 49
#define K13_SW 37
#define K14_SW 38
#define K15_SW 35 // BAD SCHEM UD+
#define K16_SW 36 // HOOKED UP TO USB NATIVE PORTS, DUMB UD-

#define P1_SW 12
#define P2_SW 24
#define P3_SW 25
#define P4_SW 26
#define P5_SW 27
#define P6_SW 28
#define P7_SW 40
#define P8_SW 41

#define KNOB_1 15
#define KNOB_2 16
#define KNOB_3 17
#define KNOB_4 18
#define KNOB_5 19
#define KNOB_6 A10
#define KNOB_7 A11
#define KNOB_8 A12

#define SLIDE_1 A13
#define SLIDE_2 A14
#define SLIDE_3 A15
#define SLIDE_4 A20
#define SLIDE_5 A21
#define SLIDE_6 A22
#define SLIDE_7 A0
#define SLIDE_8 A6

#define LED_K1 10
#define LED_K2 2
#define LED_K3 3
#define LED_K4 4
#define LED_K5 5
#define LED_K6 6
#define LED_K7 7
#define LED_K8 8
#define LED_K9 9
#define LED_K10 21
#define LED_K11 22
#define LED_K12 23
#define LED_K13 29
#define LED_K14 30
#define LED_K15 -1
#define LED_K16 -1

#define LED_P1 50
#define LED_P2 57
#define LED_P3 56
#define LED_P4 55
#define LED_P5 54
#define LED_P6 53
#define LED_P7 52
#define LED_P8 51


// USB power budget: 24 LEDs × ~20mA peak × (LED_MAX_BRIGHTNESS/255) duty + ~150mA Teensy <= 500mA
// 180/255 = 70.6% duty → ~14.1mA avg per LED → 24 × 14.1 + 150 = ~489mA max
#define LED_MAX_BRIGHTNESS 180

#endif

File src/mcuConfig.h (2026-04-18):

#ifndef mcu_config_h
#define mcu_config_h

// ============================================================
// MCU Mode Button Note Numbers — Logic Pro LED State Feedback
// ============================================================
// Logic Pro sends Note On (velocity 127 = on, 0 = off) for these functions.
// NoteRegistry routes these notes to the grid button LEDs defined below.
//
// IMPORTANT: These values are from community MCU documentation (MEDIUM confidence).
// Verify with a MIDI monitor or temporary Serial.print in handleNoteOn() before
// relying on them. See RESEARCH.md Pitfall 5 for verification procedure.
//
// To verify: open Logic, enable Serial monitor (pio device monitor), toggle
// Loop/Punch/Metronome in Logic, observe which note numbers appear in Serial output
// (add temporary Serial.print(note) in handleNoteOn if needed), then update below.

// Bank navigation (sent hardware → Logic to shift the 8-channel bank window)
#define MCU_NOTE_BANK_LEFT       46   // Bank << — shift bank 8 tracks left
#define MCU_NOTE_BANK_RIGHT      47   // Bank >> — shift bank 8 tracks right

// Track strip function note bases (MCU protocol, channel 1)
#define MCU_NOTE_ARM_BASE         0   // Arm  Ch1-Ch8: notes 0-7
#define MCU_NOTE_SOLO_BASE        8   // Solo Ch1-Ch8: notes 8-15
#define MCU_NOTE_MUTE_BASE       16   // Mute Ch1-Ch8: notes 16-23
// Input monitoring — not standard MCU, UNVERIFIED. Verify with Logic MIDI monitor
// same procedure as mode button notes in RESEARCH.md Pitfall 5.
#define MCU_NOTE_INPUT_MON_BASE  47

// MCU note numbers for transport mode state LEDs
// Loop/Cycle button state:
#define MCU_NOTE_LOOP           86
// Punch In (punch start) state:
#define MCU_NOTE_PUNCH_IN       85
// Metronome/Click toggle state:
#define MCU_NOTE_METRONOME      89

// Track SELECT notes (track selection buttons)
#define MCU_NOTE_SELECT_BASE    24  // SELECT Ch1-Ch8: notes 24-31

// Transport button notes
#define MCU_NOTE_STOP           93  // Transport: Stop
#define MCU_NOTE_PLAY           94  // Transport: Play
#define MCU_NOTE_RECORD         95  // Transport: Record

// Grid button indices (0-based) for mode LED feedback from Logic.
// K13 (index 12) is Loop — registered directly in init(), no constant needed.
// K10 (index 9) and K11 (index 10) host Punch/Metronome until reassigned.
#define MCU_PUNCH_GRID_INDEX    9   // K10 — Punch In LED
#define MCU_METRO_GRID_INDEX    10  // K11 — Metronome LED

#endif // mcu_config_h

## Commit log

2021-09-17 initial commit with pin defines
2021-11-28 basic IO working, removed LED from board bottom 4 K switches not hooked up yet
2026-02-11 add assets, STLs, cover image, and LFS tracking
    [ENCLOSURE_BOTTOM.stl, FADERS.stl, KNOBS.stl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]
2026-02-21 add stls and update gitignore
    [ALL_BUTTONS.3mf, CIRCLE_BUTTONS.stl, ENCLOSURE_BOTTOM.stl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]
2026-04-18 feat: MCU protocol foundation, LED state management, fader pickup
    Implement Mackie Control Universal protocol replacing raw CC messaging:
    - SysEx handshake state machine for DAW connection
    - MCUButton with note-based messaging and blink state machine
    - Fader class with 14-bit pitch bend on per-fader MIDI channels
    - NoteRegistry for DAW-to-hardware LED feedback
    - Fader pickup FSM (SYNCED/OUT_OF_SYNC) to prevent value jumps
    - Boot animation (pulse wave sweep) and idle ripple effect
    - Grid transport button remapping and pin fixes
    - Local SoftPWM library for LED fade control
    [inputManager.cpp, main.cpp, mcuButton.cpp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]
